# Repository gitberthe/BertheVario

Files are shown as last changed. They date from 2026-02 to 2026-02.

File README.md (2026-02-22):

# Projets BertheVario/GnuVario, BertheVarioTac et BertheVario213. 
Vario Gps parapente developés en C/C++ sous Platformio/VisualStudioCode/Code::Blocks (Software). kicad/freecad (Hardware).

**BertheVario/GnuVario :**
- firmware pour GnuVario (https://prunkdump.github.io/GNUVario-TTGO-T5-website/0-Accueil.html)
- carte mere indisponible donc pour mise a jour vario existant uniquement.
- socle pour les fichiers commun des 3 vario.

**BertheVarioTac :**
- Vario a base de ESP32-2432S028 sans la coque.
- un peut lourd pour voler et moindre autonomie d'alimentation.

**BertheVario213 :**
- Vario et coque imprimable 3d a base de Lilygo GDEM0213T5BN.
- le plus abouti des 3 vario.

**Photo des 3 vario :**

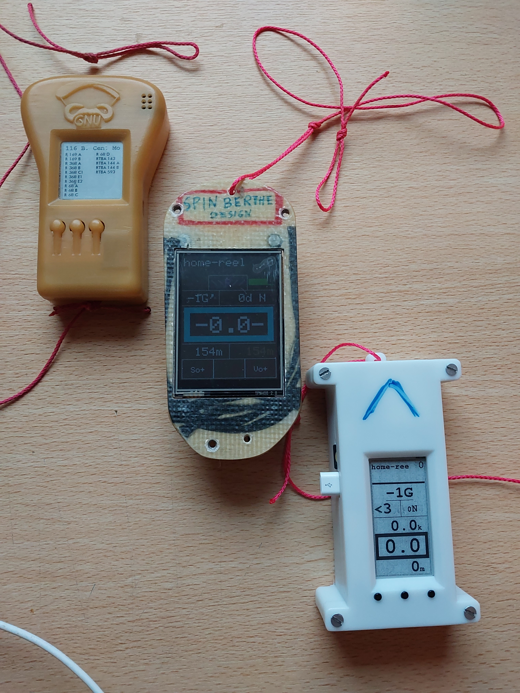
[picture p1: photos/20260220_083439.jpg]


**Logiciels annexes :**
- CompZoneAerienne : logiciel pour la creation du fichier de zone aerienne (TMA, CTR...). Visualisation des zones par fichier *.png et *.kml :
- GestHgt : logiciel pour les fichier *.hgt d'altitude sol (filtre france) et creation/verification checksum.
- IgcReader : logiciel pour relire succinctement un fichier igc (Z deco, Z attero ...) et le transformer en .kml pour googleearth.
- igc2kmz : logiciel python disponible sur le web pour creer un fichier .kmz googleearth, a partir d'un .igc (couleur fonction de Vz, altitude...) :

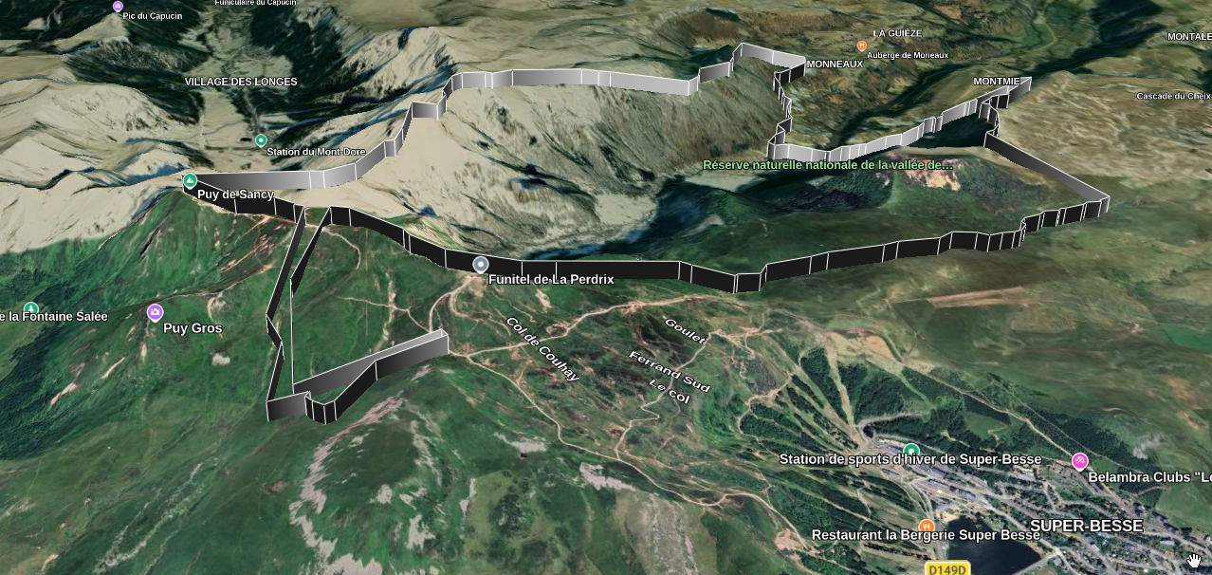
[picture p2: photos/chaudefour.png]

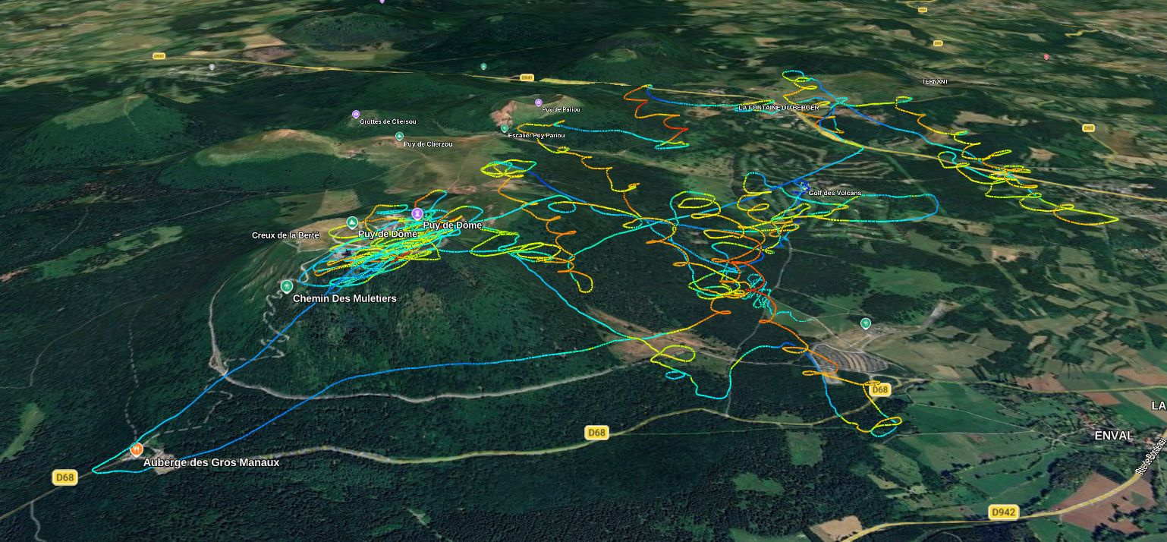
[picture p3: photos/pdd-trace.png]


zenodo :
https://doi.org/10.5281/zenodo.18722633

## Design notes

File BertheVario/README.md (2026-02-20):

# Projet BertheVario
Firmware récent du GnuVario (https://prunkdump.github.io/GNUVario-TTGO-T5-website/).
- Code C++ Visual Studio/PlateformIO pour alti-vario gps parapente (avec gestion des TMA CTR...).
- Plateforme Espressif ESP32 Dev Module, TTGO T5, Lilygo v2.4, Arduino (processeur 32bits, bi-core 240mhz).

**Utilisation / description :**
- documentation utilisateur dans /doc
- projet PlateformIO dans /BertheVarioPlatformIO
- editer/modifier avec codeblocs dans /BertheVarioCdb
- documentation developpeur dans ../../DoxyBertheVario avec le commande "doxygen Doxyfile.BertheVario" depuis /Codeblocks
- generation de fichier de zones aériennes avec /CompZoneAerienne depuis codeblocks/linux ou windows

**Important :**
- penser à bien modifier votre fichier de configuration pour un fonctionnement correct. En particulier le coefficient du filtre alti-baro (valeurs par defaut dans la documentation ou lorsque le fichier est absent/recréé mode mini-éditeur)

**Pour les développeur :**
- voire la documentation doxygen generée.
- modifier le #define de configuration du capteur magnetique pour position a plat, suspente droite ou gauche.
- fichier version.txt pour modification apportées aux differentes versions.
- modifier "BertheVarioPlatformIO/.pio/libdeps/esp32dev/ESP32 File Manager for Generation Klick ESPFMfGK/src/ESPFMfGKGa.cpp" ligne 6 : crc32.h => CRC32.h
- modifier "BertheVarioPlatformIO/.pio/libdeps/esp32dev/MPU9250/MPU9250.h" ligne 85 : 0x06 => 0x02

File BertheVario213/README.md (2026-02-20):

# Projet BertheVario213

Projet d'alti vario gps parapente (avec gestion des TMA CTR..., et mode guidage sol pour randonnée).
- Code C++ Visual Studio/PlateformIO.
- Plateforme Espressif ESP32 Dev Module, LILYGO T5 v2.3.1 GDEM0213T5BN 9102 chip, écran 2.13inch DEPG0213BN, Arduino (processeur 32bits, dual core, 240Mhz).

**La carte avec son pcb :**

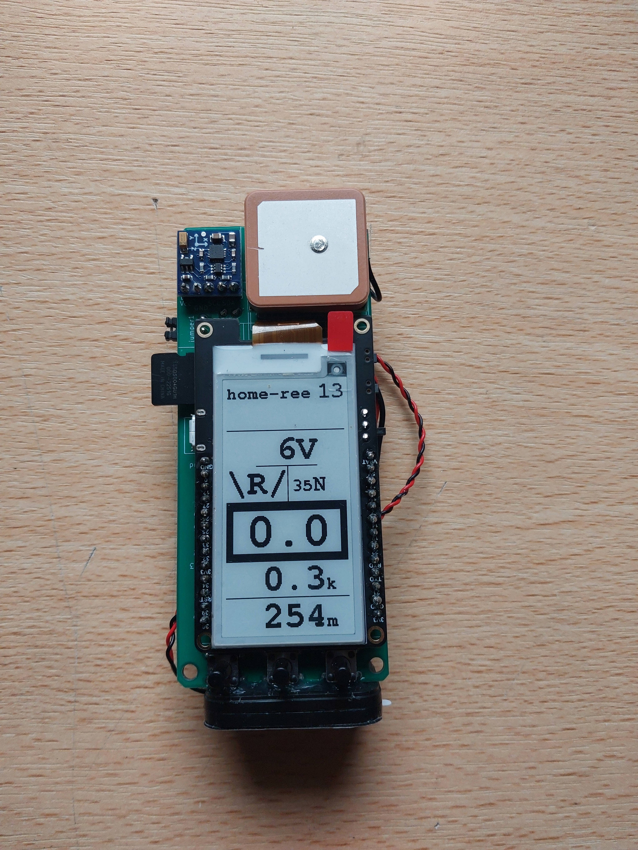
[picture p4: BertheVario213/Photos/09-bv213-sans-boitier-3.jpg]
  

**Le schema electrique :**

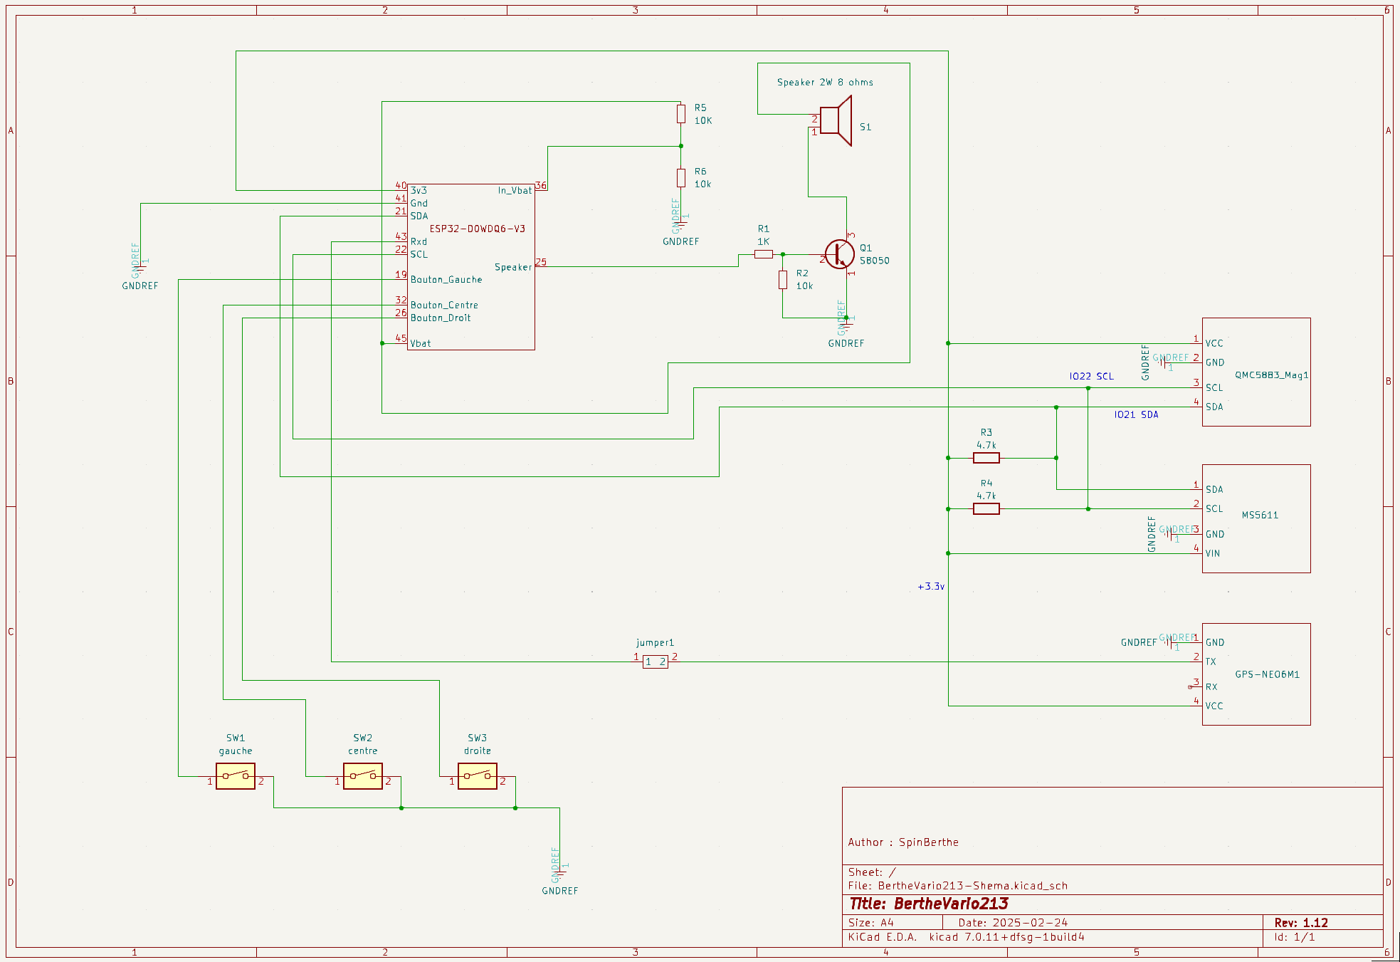
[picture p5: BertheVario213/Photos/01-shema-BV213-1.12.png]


**Le pcb :**

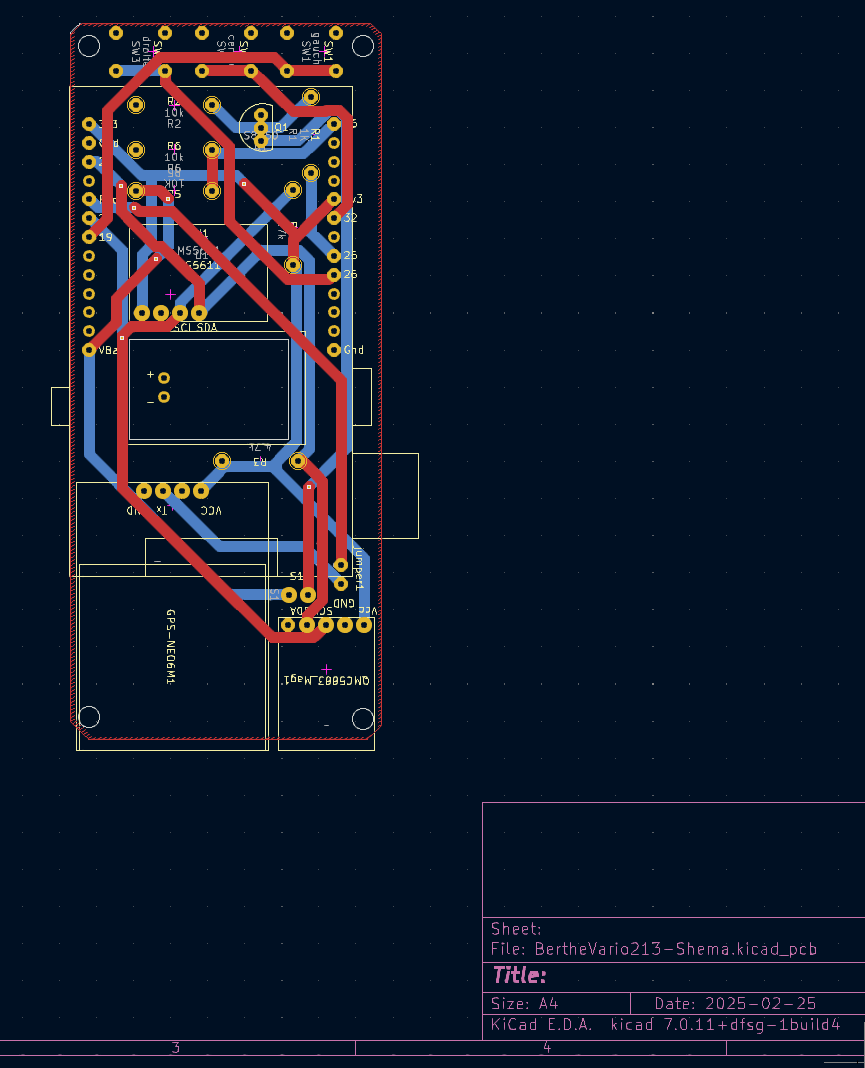
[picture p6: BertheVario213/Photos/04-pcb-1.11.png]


**Le mode randonnée :**

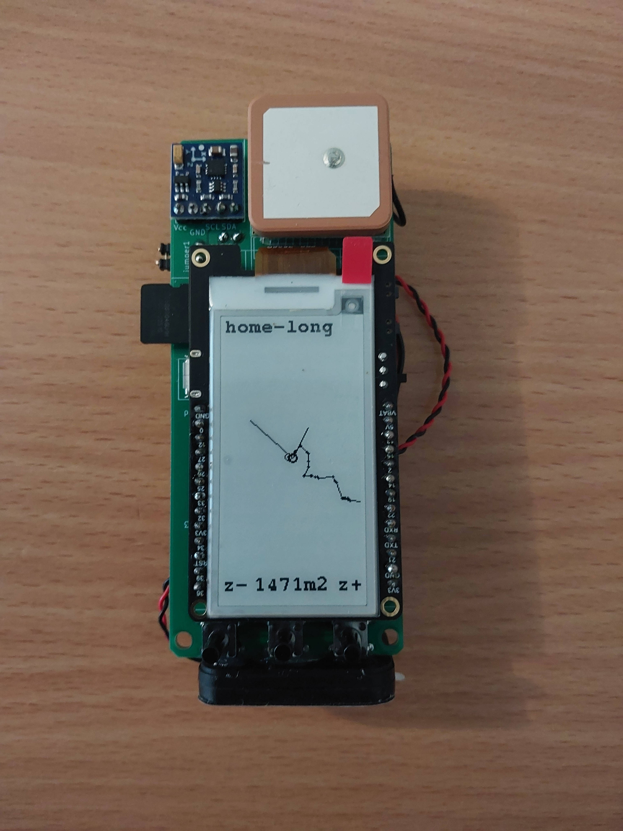
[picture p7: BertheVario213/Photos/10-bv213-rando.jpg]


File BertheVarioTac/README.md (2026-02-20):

# Projet BertheVarioTac ESP32-2432S028
Projet d'alti vario gps parapente tactile (avec gestion des TMA CTR..., et mode guidage sol pour randonnée).
- Code C++ Visual Studio/PlateformIO.
- Plateforme Espressif ESP32 Dev Module, 2.8inch ESP32-2432S028, Arduino, ESP32-WROOM-32,  (processeur LX6 32bits, bi-core 240mhz).

**Utilisation / description :**
- documentation utilisateur et autre dans /documentation
- projet PlateformIO dans /BertheVarioTacPlatformIO
- editer/modifier avec codeblocks dans /Codeblocks
- documentation developpeur dans ../../DoxyBertheVarioTac avec le commande "doxygen Doxyfile.BertheVarioTac" depuis /Codeblocks

**Pour les développeur :**
- voir la documentation doxygen generée.

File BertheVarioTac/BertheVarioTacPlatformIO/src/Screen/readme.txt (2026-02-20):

Fichier necessaires à la compilation de l'ecran :
 cp ./src/Screen/User_Setup.h ./.pio/libdeps/esp32dev/TFT_eSPI/User_Setup.h
 cp ./.pio/libdeps/esp32dev/LovyanGFX/examples/Advanced/LVGL_PlatformIO/src/lv_conf.h src/Screen

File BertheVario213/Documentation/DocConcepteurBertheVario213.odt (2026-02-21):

Documentation Concepteur BertheVario213

Projet d’alti vario gps parapente

à base de

LILYGO T5 v2.3.1 DEPG0213BN 9102 chip

Version 20260219a

https://github.com/gitberthe/BertheVario

Compilé avec Visual Studio Code / PlatformIO

Espressif Systems

ESP32 Dev Module

ESP32-D0WDQ6-V3

écran 2.13inch DEPG0213BN

Arduino

langage C++.

gitberthe@gmail.com

# Mise en place de l’environnement logiciel :

Le logiciel est compilé avec Visual Studio Code / PlatformIO.

* La librairie pour le gestionnaire de fichier Wifi doit être modifiée si la version est trop vieille.

Dans BertheVarioTacPlatformIO/.pio/libdeps/esp32dev/ESP32 File Manager for Generation Klick ESPFMfGK/src/ESPFMfGKGa.cpp" ligne 6 : crc32.h => CRC32.h

La compilation du logiciel peut alors s’effectuer.

# Connexion de la batterie :

Connecter la batterie à la carte ESP32 à l’aide du connecteur fournit. Une batterie 4,2v 1S lipo 2000 mah 103450 est suffisante. Elle se recharge par le connecteur usb.

# haut parleur :

Le haut parleur est un haut parleur 2W 8 ohms.

# Téléchargement du firmware :

Pour télécharger le firmware il y a 2 façons :

- soit par câble usb avec platformio ou un autre logiciel. Il faut impérativement retirer le cavalier de la donnée gps pour que le téléchargement se face.

- soit par wifi et carte sd. Il faut alors mettre le fichier BertheVario213/BertheVario213PlatformIO/p_pio/build/esp32dev/fimrware.bin à la racine de la carte SD. Puis rebooter avec les boutons gauche et droit. Lors du prochain demmarrage le vario ce mettra à jour puis rebootera.

# Quelques photos :

La carte de base ESP32 LILYGO T5 v2.3.1 GDEM0213T5BN 9102 chip avec son écran 2,13 inch DEPG0213BN:

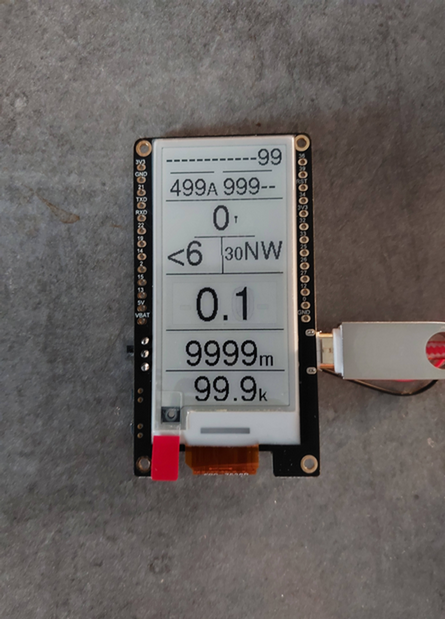
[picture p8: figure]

Attention : Prévoir un film filtre uv car il ne résiste pas au soleil cet écran.

Le circuit imprimé avec ses composants sur les 2 faces. Attention au sens du gps, capteur magnétique, barométrique, et transistor.

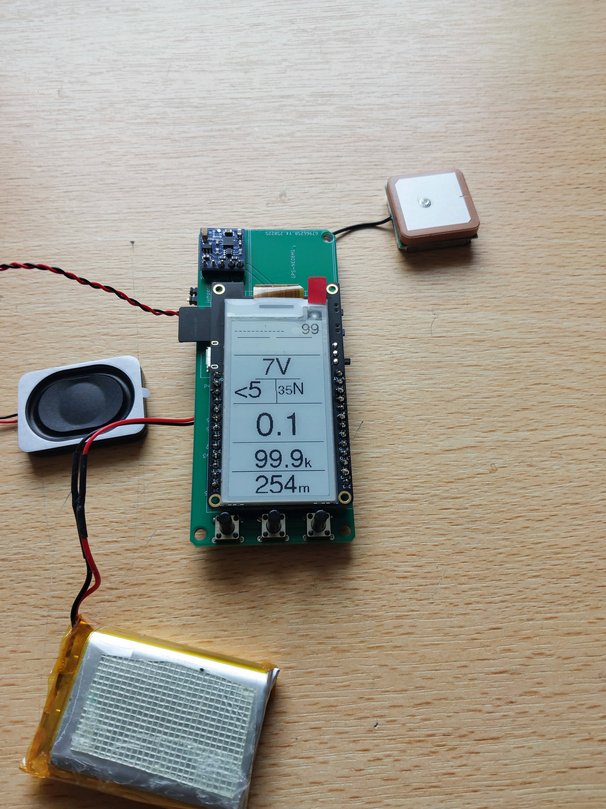
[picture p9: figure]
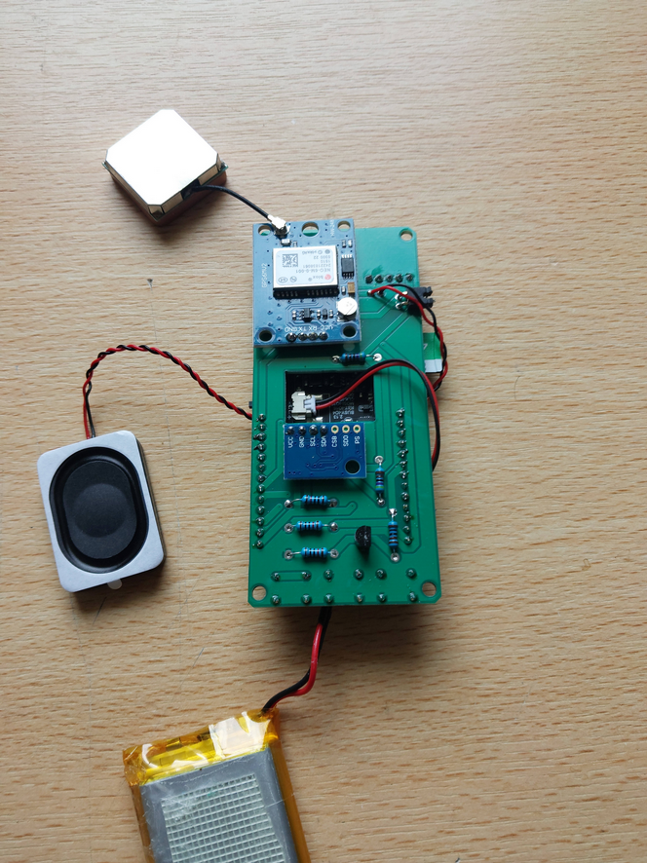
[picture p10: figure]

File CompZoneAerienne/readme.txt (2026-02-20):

projet pour creer le fichier des zones aeriennes.

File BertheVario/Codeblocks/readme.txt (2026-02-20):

- Ce repertoire est present uniquement pour editer/modifier les sources sous codeblocks
- utilisation aussi pour generer la documentation code dans ../../DoxyBertheVario : doxygen Doxyfile.BertheVario

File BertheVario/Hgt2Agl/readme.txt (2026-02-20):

projet pour tester les fichier *.hgt hauteur sol.

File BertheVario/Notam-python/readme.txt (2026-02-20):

!!!! projet non fonctionnel !!!!

- script python pour extraire les notams du site sofia-briefing
- en colaboration avec c.joyez@free.fr

- a poursuivre : saisie de la date, heure et nom aeroport de depart en parametre de la ligne de commande

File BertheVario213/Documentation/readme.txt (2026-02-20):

Documentation utilisateur pour description de l'ihm, des boutons et des fichiers de la carte sd.
Documentation concepteur pour description succinte de l'environnement lociciel et du telechargement firmware.

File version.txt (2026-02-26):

le 20260226a :
 - hauteur sol attero 90m pour les 3 vario
 - son vario pour BertheVario213

le 20260223a :
 - mise en conformite de BertheVarioTac pour le regroupement de l'activation 
   de zones.

le 20260220a :
 - creation de https://github.com/gitberthe/BertheVario pour les 3 varios : 
  . BertheVario/GnuVario
  . BertheVarioTac
  . BertheVario213

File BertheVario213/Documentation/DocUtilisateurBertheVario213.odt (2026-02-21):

Documentation Utilisateur BertheVario213

Projet d’alti vario gps parapente

à base de

LILYGO T5 v2.3.1 DEPG0213BN 9102 chip

Version 20260219a

https://github.com/gitberthe/BertheVario

Compilé avec Visual Studio Code / PlatformIO

Espressif Systems

ESP32 Dev Module

ESP32-D0WDQ6-V3

écran 2.13inch DEPG0213BN

Arduino

langage C++.

gitberthe@gmail.com

Modifications apportées à la documentation :

20260219a : Modification Ihm.

20250322b: Chapitre 21 mode randonnée.

20250322a: Création documentation utilisateur d’après BertheVario.

# Écran de boot :

A l’écran de boot, il y a possibilité de changer de mode (voir boutons plus bas). Puis il y a affichage de la tension de batterie, du pourcentage batterie et du numéro de firmware.

Une batterie à 4,3v est chargée, à 3,7v vide.

Initialisation du hardware : 1 beep, à la mise sous tension.

Remarque 1 : en mode connexion wifi, les identifiants sont ceux stockés sur la carte SD dans le fichier /config/config.txt.

En mode connexion wifi, il suffit de taper dans un navigateur web http://x.x.x.x:8080 (adresse IP données par l’écran) pour avoir accès à la page téléchargement si dessous (accès au fichiers IGC par clic sur le lien, éditer, renommer. détruire, prévisualiser.)

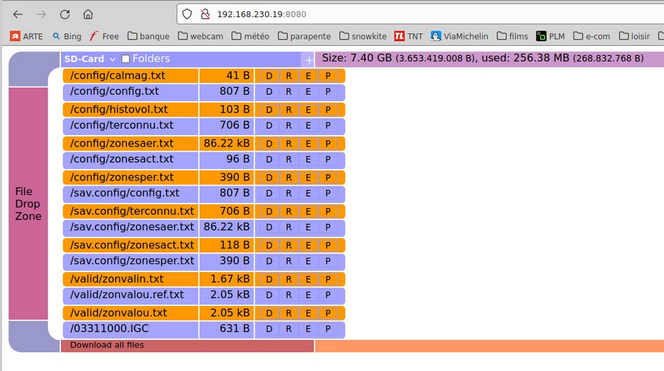
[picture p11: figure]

Remarque 2 : En mode calibration du capteur magnétique. Il faut faire des 8 avec le BertheVario213 jusqu’à re-démarrage (maximum de directions possible dans le sens du cap magnétique).

Il y a mise a jour du fichier /config/calmag.txt sur la carte SD qui est nécessaire au bon fonctionnement du capteur magnétique.

Bien sur, faire des 8 en position à plat ou verticale suivant la configuration firmware “à plat” “ou “suspente gauche ou droite”.

Remarque 3 : Dans les pages ihm du milieux, si on appuie sur le bouton gauche et droit, mais pas sur le bouton centrale, il y a alors reboot du BertheVario213.

Boutons :

Gauche : mode calibration.

Central : mode wifi.

Droit : mode rando-vol. Ou verification cheksum des *.hgt si appuy multiple.

Gauche et droit : reboot.

# Démarrage :

Après le boot et l’initialisation du hardware, il y a démarrage du logiciel et 2 beep. S’il y a 4 beep, c’est qu’il y a un problème de carte SD. Puis il y a affichage de l’écran 0 Vz.

# Écran Vz :

Cap Magnétique

à plat

Nom terrain et finesse

Temps de vol

Tension batterie

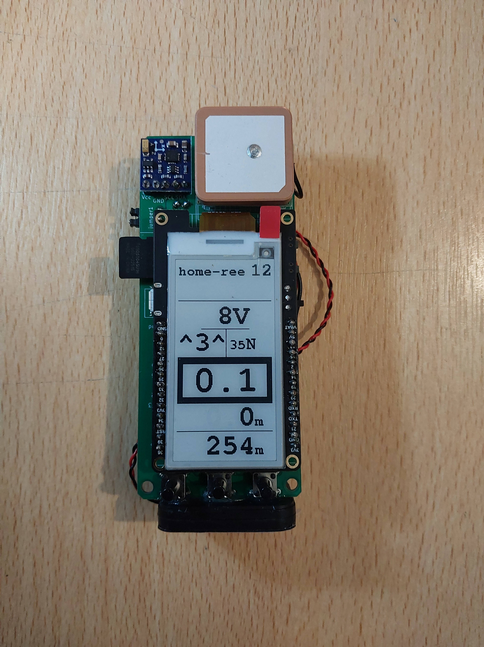
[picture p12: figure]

Cap Sol/Gps

Dérive Sol

Vitesse verticale / finesse sol

Altitude/Hauteur sol

Vitesse Sol

Bouton central

Bouton gauche

Bouton droit

Important : Un appui long sur le bouton centre permet de re-effacer l’écran pour le remettre propre.

Boutons :

- gauche court : activer/désactiver le son d’attente gps G/S/V et/ou alarmes/pré-alarmes pénétration Tma/Zones.

- gauche long : page précédente (bloqué en vol).

- central : page suivante (bloqué en vol).

- central long : raz de l’écran.

- droit court/long: démarrage forcé du vol ( Gps mode S/V) / arrêt du vol ( si < 5kmh et 0,4m/s).

Cap magnétique : le cap est indiqué suivant la direction de la flèche. Il doit avoir été calibré au moins une fois (fichier /config/calmag.txt, voir séquence de boot)

Dérive sol : la dérive sol est indiquée en dizaine de degrés <<4 gauche, 5>> droite ou ^1^ tout droit. \R/ indique une reculade avec alarme sonore désactivable. Gauche indique que l’on dérive a gauche par rapport au cap magnétique.

Nom terrain et finesse / direction et distance du terrain : Indique le nom du terrain d’atterrissage le plus proche et sa finesse pour l’atteindre.

Cap sol : cap issue du gps en dizaine de degrés. Indication Nord, Nord Est ...

Vitesse sol : vitesse issue du gps en km/h. Hauteur sol barométrique en mètres.

Vz : Vz du capteur barométrique. Si la Vz est cerclée de noir c’est qu’elle est négative.

Altitude : Altitude barométrique recalée altitude sol en mètres. Le recalage sol est effectué toutes le 10 sec au sol avec l’emmission d’un bip caracteristique. A verifier au moment de la pré-vol.

Temps de vol : Temps de vol en minutes.

‘-1G’ indique une attente de données GPS (voyant rouge clignotant) (émission d’un bip toutes les 5 secondes).

‘ 8S’ indique une attente de stabilisation des informations longitude, altitude, 8 satellites en vue (émission d’un bip toutes les 5 secondes).

‘10V’ indique une attente de la vitesse sol importante pour le démarrage de l’enregistrement du fichier IGC de trace GPS, 10 satellites en vue. (émission de 2 bips toutes les 5 secondes si pas hinibé avec le bouton gauche)

Les fichier IGC générés sont sous la forme MMJJHHmm.IGC dans la carte SD à la racine au rythme d’un point par seconde.

Émission de 3 beep au démarrage de l’enregistrement IGC.

Il peut y avoir arrêt de vol et redémarrage des taches en mode “S” (3 bips) si l’on ne vol plus pendant 4 secondes (vitesse sol petite, hauteur sol petite...)

Il y a aussi arrêt du vol si on appui sur la touche droite.

Nom terrain et finesse : Conformément au fichier “/config/terconnu.txt” de la carte SD. Affichage du terrain accessible avec la plus petite finesse. Et affichage de la finesse pour l’atteindre.

Remarque 1 : Il y affichage de la TMA/CTR/Zone protégé pénétré (avec son altitude) à la place du nom terrain finesse si l’on est dedans une zone (voir fichier /config/zonesaer.txt). (3 bips caracteristiques si dans la zone).

Be TMA 5.1 al:3500m indique que l’on est en “below” en dessous de la TMA 5.1 qui commence a une altitude de 3500m ce jour.

In TMA 2.3 al:1980m indique que l’on est en “in” on a pénétré la TMA 2.3 qui commence a une altitude de 1980m.

Zp PROTECT Reserve naturelle al: 0m indique que l’on a pénétré une zone protège (en dessous de 1000/ … /50m sol).

Remarque 2 :On peut déclencher un début de vol par le bouton droit en écran Vz (sans stabilisation gps). On peut arrêter un vol aussi par le bouton droit si la vitesse sol est < 5kmh et la Vz < 0,6m/s.

# Écran Histo:

On accède à l’écran Histo par un appui sur le bouton centre après l’écran Vz. L’écran revient à l’écran Vz au bout de 15 secondes.

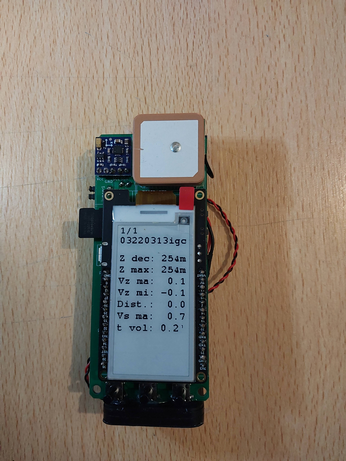
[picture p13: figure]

L’écran Histo contient le nom du fichier Igc, la Z décollage, la Z max, la Vz Max, la Vz Min, la distance parcourue, la Vs Max et le temps total du vol. Ces informations sont issues des fichiers “/histo/nom_igc.his”.

Boutons :

- gauche long : page précédente.

- central : page suivante.

- central long : raz de l’écran.

# Écran Affichage / Archivage IGC :

Ces 2 écrans entre les écrans historique du dernier vol et gestion des TMA permettent :

- pour l’écran affichage igc, affichage des temps des fichiers IGC sur la carte SD et calcul de leur total en minutes decimale (si vol supérieur à 30 secondes).

- pour l’écran archivage (bouton gauche/droite, permet d’archiver tous les fichiers IGC de la carte qui sont à la racine. Dans le répertoire /arch/annee. Destruction des vols < 1 min.

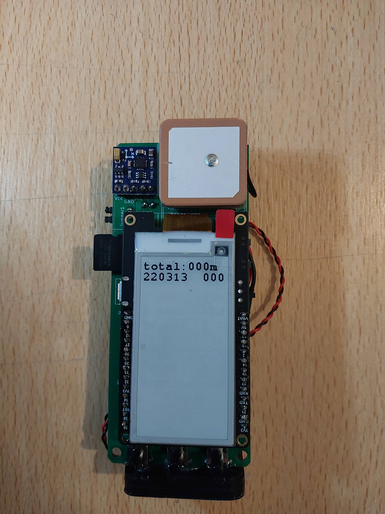
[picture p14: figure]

Boutons :

- gauche long : page précédente.

- central : page suivante.

- central long : raz de l’écran.

- gauche/droit : archivage fichier igc. (central annulation)

# Écran Zone Aériennes / Modification :

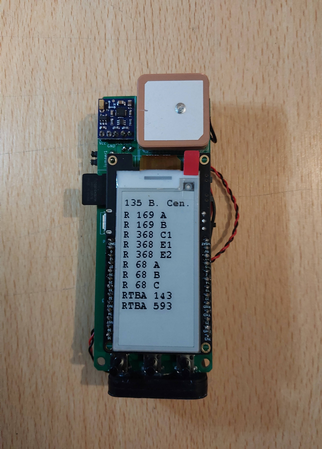
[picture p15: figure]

On accède à l’écran zone aériennes par un appui sur le bouton centre depuis histo. L’écran revient à l’écran 0 au bout de 15 secondes. Cet écran est pour la gestion des zones aériennes. On a le nombre de zones aériennes en mémoire, ainsi que le nom des zones modifiables activées. Celles non modificables ou désactivée ne sont pas affichées.

Depuis l’écran zone aérienne, avec un clic droit/gauche on passe à l’écran modification pour lire ou modifier l’activation des zones. L’écran revient à l’écran Vz au bout de 15 secondes. Les boutons gauche/droit font défiler les zones, le bouton centrale peut modifier l’activation de la zone en cour (si elle est mod et pas const). Pour les zone modifiables (ex :R68 ou R368) voir le fichier config/zonesact.txt)

Il y a affichage à l’écran modification des informations nom, activation modifiable (mod) ou figée (const), altitude basse hors période, période début JJ-MM, période fin JJ-MM, altitude basse période semaine, altitude basse période week-end. Si la zone est « protect » ou « ffvl-prot », affichage de la hauteur sol minimale de survole (ex : Chastreix, Chaudefour, Parc des Cevennes, Gypaete barbu...)

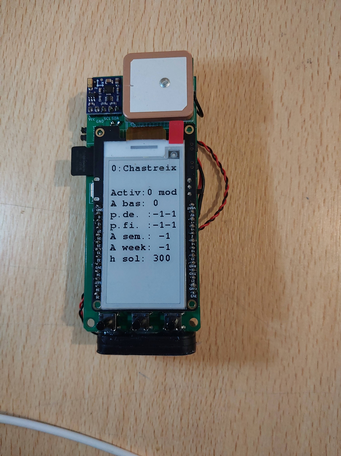
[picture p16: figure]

Boutons :

- gauche long : page précédente.

- central : page suivante. si mode navigation zone : activation/désactivation Tma/Zone

- central long : raz de l’écran.

- gauche/droite : mode navigation dans Tma/Zone et retour page Tma global.

- long G/D début/fin Tma/Zones si mode navigation Tma/Zone.

La modification de l’activation de la zone est mémorisée dans le fichier /config/zonesact.txt. Et seul les zones présente dans ce fichier sont modifiable. Le format est : nom_zone;0;. Il faut donc le générer une première fois avec un éditeur de texte, pour pouvoir le modifier par la suite.

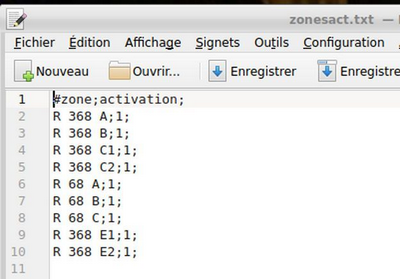
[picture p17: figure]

Remarque :

Les zones ne figurant pas dans ce fichier sont considérées comme toujours actives.

Il y a regroupement de zone suivant les 2 permier champ. Ex : R_68 modifiera R_68_A et R_68_B...

La totalité des zones sont dans le fichier /config/zonesaer.txt, voir plus bas pour le générer.

La configuration des périodes est dans le fichier /config/zonesper.txt. Il est de la forme :

nom zone;nom affichage;début période;fin période;alti semaine;alti week-end

ex : TMA CLERMONT 2.1;TMA CFD 2;15-03;15-10;1980;1980

Nom zone est le nom dans le fichier /config/zonesaer.txt, les 3 premiers champs. Nom affichage est le nom de remplacement à l’affichage, puis JJ-MM début période, JJ-MM fin de période, altitude période semaine, altitude période week-end.

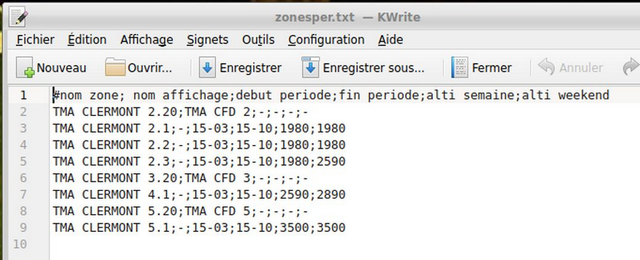
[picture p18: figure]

# Écran Éditeur Configuration:

On accède à l’écran éditeur par un appui sur le bouton centre après l’écran TMA. On a alors accès a un mini éditeur du fichier de configuration. On peut ainsi modifier les variable par bouton central, puis G/D pour incrémenter / décrémenter. Ex 1: [dtu] => augmentation/diminution de 1 avec les boutons. Ex 2 : [vz_seuil_haut] => augmentation/diminution de 0,05 avec les boutons C/G/D. Les modifications sont automatiquement pris en compte et sauvegardées dans le fichier de configuration /config/config.txt dès le retour à une autre page. S’il n’y avait pas de fichier, un fichier par défaut est créé.

Important :

Le coefficient de filtrage Vz doit etre à 0,85.

Boutons :

- gauche long : page précédente.

- central : page suivante. si mode navigation variables : mode modification/navigation variable.

- central long : raz de l’écran.

- gauche/droite : navigation dans variable et sortie de navigation variable. Incrémentation/décrémentation variable si mode modification.

- long G/D début/fin variable si mode navigation variable.

# Écran Tma Dessous:

On accède à l’écran Tma dessous par un appui sur le bouton centre après l’écran éditeur. On a alors accès à la Tma sous laquelle on est, avec son altitude. Ainsi que les coordonnées du point gps en cours.

Boutons :

- gauche long : page précédente.

- central : page suivante. Annulation mémorisation point.

- central long : raz de l’écran.

- gauche/droite : mémorisation point courant dans le fichier des terrains connus. Exemple : mémoriser un nouveau terrain d’atterrissage.

# Écran Système :

On accède à l’écran système par un appui sur le bouton centre âpres l’écran Tma dessous. L’écran revient à l’écran Vz au bout de 15 secondes. Cet écran est plus informations système avec date et heure, cap magnétique, pourcentage d’utilisation core 0 et 1, température à l’intérieur du boîtier, mémoire libre en octets, tension batterie, et numéro du firmware. Pour info, une zone aérienne prend de 1 à quelques ko suivant sa taille. Il y a donc de la marge dans le cas ci-dessous.

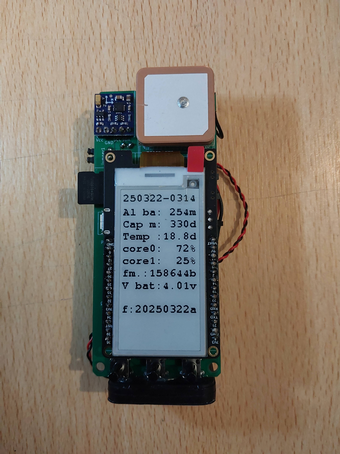
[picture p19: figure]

Boutons :

- gauche long : page précédente.

- central : page suivante.

- droit long :

# Fichier de configuration SDCard/config/config.txt :

Le fichier de configuration doit être placé dans le dossier /config a la racine de la carte SD. La carte SD contient aussi les fichier IGC générés par un vol (ou un faux vol de 12 secondes).

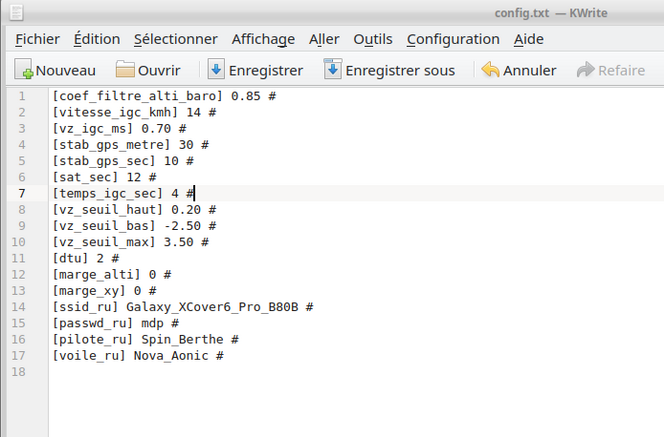
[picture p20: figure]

Compléter les informations nécessaires dans ce fichier. Les # sont des commentaires, pour le mot de passe, ssid, pilote et voile les ‘_’ sont remplacés par des blancs/espaces.

Le fichier est généré automatiquement si vous passer une fois en page mini éditeur s’il n’existait pas auparavant avec les valeurs par défaut.

[coef_filtre_alti_baro] : filtrage alti baro, valeur [0,1[, 0.999 donne un très grand filtrage mais un léger retard dans la valeur. 0. ne filtre rien et donne par conséquent des beep intempestifs. Mettre 0.85 pour un filtrage correct.

[vitesse_igc_kmh] : vitesse sol de déclenchement de l’enregistrement. Début de vol déclenché au bout de temps_igc_sec secondes de vitesse successive supérieur à (14km/h par défaut). S’il y a faux départs de vols cause imprécision gps, ne pas bouger le temps de la détection de stationnarité (quelques secondes). Il y a alors redémarrage des taches automatiquement en mode S/V.

[vz_igc_ms] : + ou - vitesse verticale pour déclencher un vol (0,6 par défaut).

[vz_seuil_haut] : Vz ascendante de déclenchement des beeps aiguës (0,2 par défaut).

[vz_seuil_bas] : Vz descendante de déclenchement des beeps grave (-2,6 par défaut).

[vz_seuil_max] : Vz ascendante des beep vario maximum très aiguës (4 par défaut).

[alarme_reculade] : activation alarme sonore reculade (désactive par défaut).

[ssid_ru] : nom wifi pour téléchargement des IGC via navigateur web. (underscores remplacés par des espaces)

[dtu] : heure a ajouter a l’heure gps pour le nom des fichiers *.igc.

[passwd_ru] : mot de passe wifi (underscores remplacés par des espaces)

[pilote_ru] : nom de pilote dans le fichier igc (underscores remplacés par des espaces)

[voile_ru] : nom de voile dans le fichier igc (underscores remplacés par des espaces)

# Fichier de terrains connus SDCard/config/terconnu.txt :

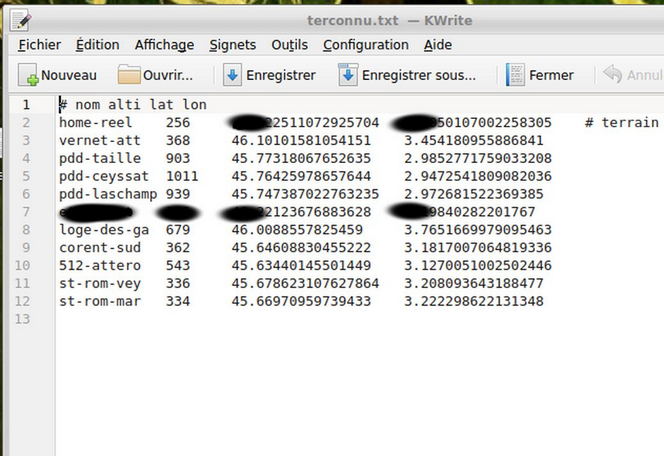
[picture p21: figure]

Comme vous pouvez le voir, ce fichier liste les terrains connus avec leur nom de 10 caractères maximum ainsi que leur coordonnes. Utile pour avoir la finesse du terrain le plus proche. Et pour générer les zones aériennes autour de ces points.

De plus ce fichier peut etre utilisé pour generer les zones aériennes (rayon autour des points)

# Fichier de calibration SDCard/config/calmag.txt :

Ce fichier est généré automatiquement par appuis au boot sur le bouton gauche. Faire des 8 avec le boîtier jusqu’au redémarrage pour calibrer le capteur magnétique.

# Fichier d’historique de vol SDCard/config/histovol.txt :

Ce fichier est généré automatiquement à chaque nouveau vol. Il est lu pour afficher l’écran 1. Sa forme est la même que celle dur fichier “/config/config.txt”.

# Fichier IGC :

Les fichier IGC sont téléchargeable en mode wifi (voir séquence de boot) et peuvent être visualisés sur le web avec https://e-logbook.org par exemple. Ils contiennent les date et position pour chaque seconde. L’altitude GPS qui est fausse a 50m près souvent, c’est pour cela que je ne la met plus. Il contient aussi l’altitude barométrique qui est recalée altitude sol pendant la phase S stabilisation (il est donc important de laisser le vario au sol pendant cette phase). Cette dernière est assez précise (10cm normalement) pour peut que l’on ai laissé le GPS immobile pendant la phase S, le temps qu’il se cale bien en lat/lon pour extraire la bonne altitude des fichier *.hgt. On a alors un fichier IGC précis à quelques mètres. Que l’on peut convertir en kml avec http://meles.work/igc/igc.html.

# Carte SD :

La carte SD doit etre formaté en fat16/fat32 les fichiers “/config/terconnu.txt”, “/config/config.txt”, “/config/calmag.txt”, “/config/zonesaer.txt”, “/config/zonesact.txt” et “/config/zonesper.txt”. Et les fichiers generes “/config/calmag.txt” et “/histo/nom_igc.his”. Les fichiers *.IGC sont créées à la racine.

Elle contient aussi les fichiers de validation de zone “/valid/zonvalin.txt” et le fichier généré au boot wifi “/valid/zonvalout.txt”.

Important : Pensez a installer aussi les fichier de hauteur sol *.hgt, pour toute la france, dans le repertoire "/config/hgtdata". Ceci est obligatoire car il y a recalage d’altitude barométrique avec ces fichiers avant le decollage ( https://www.viewfinderpanoramas.org/Coverage%20map%20viewfinderpanoramas_org3.htm ).

# Rechargement du GnuVario :

Utiliser un cable micro-usb. Une recharge complète prend plusieurs heures. La tension de la batterie doit être à 4,3v en pleine charge (3,7v déchargée). La tension de la batterie est affichée a l’écran de boot ou en page sys, ainsi que en page Vz par le train en gras au dessus du temps de vol.

# Le Gps :

Bien entendu le Gps accroche mieux en pleine nature qu’en ville, en terrain découvert que sous les arbres, par ciel clair que pluvieux, à l’arrêt qu’en déplacement. Attendre l’affichage d’une altitude cohérente à l’écran avant de faire le vol (recalage altitude barométrique par altitude sol jusqu’à la stabilisation gps).

# Les zones aériennes et le fichier SDCard/config/zonesaer.txt :

Les zones aériennes qui sont traversées sont affichées en lieux et place de “terrain connu accessible”. Si l’on traverse une zone aérienne, il y a affichage du nom de la zone ainsi de que sont altitude minimale avec une alarme sonore (l’altitude est fonction de la zone, de la date en ou hors périodes, et de la semaine ou du week-end dans la période). L’alarme sonore est activable/désactivable par le bouton du milieu.

Peut de zones tiennent en mémoire du GnuVario. Donc, pour ce faire, il faut prendre le fichier PlatformIO/Projects/CompZoneAerienne/data/20240615_ffvl-cfd.geojson (disponible sur le net, fichier generer par “Pascal Bazile” http://pascal.bazile.free.fr/paraglidingFolder/divers/GPS/OpenAir-Format/download.php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 ) et le découper avec le programme PlatformIO/Projects/CompZoneAerienne/CompZoneAerienne qui compresse les zones à fort nombre de points (itération 3 points distance à la droite < 4,5 mètres) ..

Utilisation : CompZoneAerienne lat_centre_deg lon_centre_deg rayon_km > zonesaert.txt. Ou CompZoneAerienne –batch terconnu.txt rayon_km > zonesaert.txt pour utilisation du fichier des terrains connus. Le programme enregistre alors dans le fichier toutes les zones coupant les cercles définit par leur centres et rayons des points connus. Il suffit de placer ce fichier sur la carte SD/config.

Attention : Si le fichier est trop gros, il plante le GnuVario au boot lors de sa lecture. C’est pour cela qu’il y a des zones réduites en nombre de points par CompZoneAerienne, Ceci est fait lors de la génération du fichier. Comme pour les zones protégées “PROTECT” qui ont un énorme nombre de points de définition (1800 pour Chaudefour)(Validation Gnuplot très acceptable). L’algorithme utilisé est la suppression des points proches d’une droite.

De plus, pour gagner en mémoire il y a un algorithme de compression de données de float 32bits vers short 16bits dans le firmware. Les zones ont ainsi une résolution variable de 1 à 7 mètres par rapport aux zones du fichier. En moyenne la résolution est de 1,95metres. Si il y a un problème de compression short il y a beep et reboot.

Remarque : Les fichiers *.hgt nécessaire au calcul de la hauteur sol sont a mettre dans le répertoire “SdCard/config/hgtdata” (à télécharger sur https://www.viewfinderpanoramas.org/Coverage%20map%20viewfinderpanoramas_org3.htm). Il y a test de présence au démarrage du centre de la France.

Important : Le GnuVario a été activement teste pour différent sites d‘Auvergne, a différentes périodes, altitudes et marges XY Z. Je décline toutes responsabilité quand à sa fiabilité à ce sujet (on est jamais à l’abri d’un oubli dans l’algorithme), en Auvergne et encore moins dans une autre région. Les zones étant bien imbriquées, vérifier par procédure de test, au moins un point par zone, que le comportement est correct chez vous. Pour cela il y a 2 façons :

- Rappel : dans la page “histo ecran 1”, la zone et le plafond courant sont affichés.

- Utiliser le fichier /valid/zonevalin.txt de la carte Sd. Puis booter en wifi. Il y a alors génération de /valid/zonevalou.txt avec les résultats.

Zonevalin.txt est de la forme :

#ville;lon,lat;annee,mois,jour;altitude,marge_xy,marge_z;zone a_active,zone_b_active;

Zonevalou.txt est de la forme :

numéro_ligne;ville;date;TMA;altitude_plafond;alarme_générée;

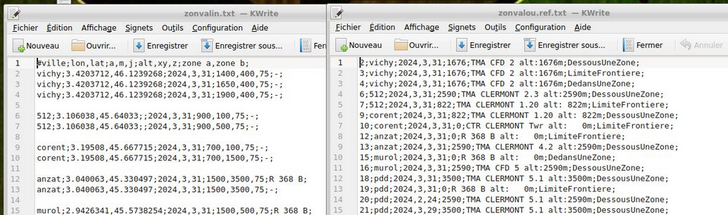
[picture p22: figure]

Remarque :

Voir le logiciel CompZoneAerienne/zones_gnuplot et zones_kml pour avoir le dessin des zones. Sous forme de fichier *.png ou *.kml pour google earth.

# Pour les développeur :

Pour ceux qui veulent recompiler le programme pour leur écran ou autre. Installer Visual studio code sur linux (ou Windows) comme préconiser sur https://prunkdump.github.io/GNUVario-TTGO-T5-website/code/ide_platformio.html (avec plateforme IO et board espressif ESP32 Dev module).

Copier les dossiers de https://github.com/gitberthe/BertheVario213 dans ~/Documents/PlatformIO/Projets.

Ouvrir le projet BertheVario213PlatformIO. Modifier les fichiers désirer, et en particulier les // commentaires dans les fichier BertheVario213PlatformIO/src/BertheVario213.h et ses différents #define DEBUG_XYZ.

Puis compiler/uploader le firmware (petite fleche en bas à gauche de VSCode, port /dev/ttyACM0 sous linux) de préférence sans la carte SD. Ca reboot automatiquement le BertheVario213.

Débogage par “Moniteur Serie”.

Important : attention si vous réinstallé VsCode (apparemment avec github et pull):

- modifier "BertheVario213PlatformIO/.pio/libdeps/esp32dev/ESP32 File Manager for Generation Klick ESPFMfGK/src/ESPFMfGKGa.cpp" ligne 6 : #include <crc32.h> en <CRC32.h>.

Rappel : Pour ceux qui veulent recompiler CompZoneAerienne et ainsi générer leur propre zones, le faire sous codeblocks, aussi bien sous windows que sous liux.

Pour windows voir le programme et ses .dll déjà compilées dans le dépôt https://github.com/gitberthe/BertheVario213

# Le mode randonnée pour ne plus se perdre :

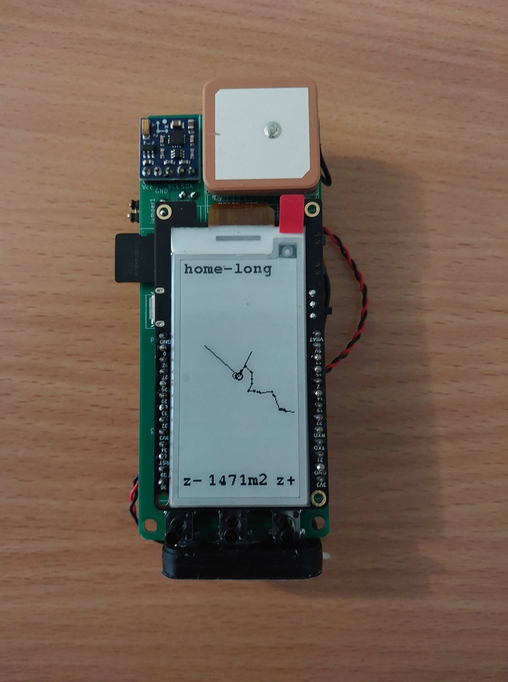
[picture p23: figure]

Trace du fichier Gpx

Echelle de la carte

Nom trace courante

Zoom + et -

Nord magnetique

Cap Gps

Position courante

Le mode randonnée est un mode de guidage terrestre pour rejoindre un décollage inconnu par exemple.

Il est accessible au boot par l’appui sur le bouton droit (rappel : gauche calibration magnétique, centre filemanager wifi, gauche et droite reboot).

Au démarrage, il y a acquisition du Gps. Puis une fois le Gps fonctionnant, il y a lecture des fichiers *.GPX du répertoire /SdCard/Gpx, ainsi que du fichier des terrains connus et d’un fichier similaire ptremarq.txt. Et affichage quelques secondes des traces/points les plus proches (rappel on peut télécharger les fichiers par wifi, drag&drop).

Suivant la position Gps, la trace/point gpx la plus proche est chargée en mémoire au bout de quelques secondes. On peut sélectionner une autre trace par les boutons gauche/droite/centre. Le guidage alors commence.

A l’écran on a :

- Le nom de la trace du fichier gpx (8 caractères maximum + 3 pour l’extension). Le nom de la trace est celui dans le fichier (la balise <name>) et peut être modifiée avec un éditeur de texte standard.

- La grande ligne est le nord magnétique issu du capteur magnétique (qui doit être calibré bien sur). Dans mon cas le haut du BertheVario213 mais ça dépend de la compilation (fichier BerheVario213.h #define VARIO_CAP_MAG_A_PLAT 1 2 ou 3).

- La trace gpx, orientée au nord, à l’échelle indiquée en mètres carrés pour la surface de l’écran.

- Les touches gauche/droite pour zoom fois 2, divisé par 2.

- le centre de l’écran est la position actuelle.

- La petite ligne est le cap gps.

Donc en alignant le nord magnétique en haut de la carte on peut se situer par rapport à la trace. Le petit rond de la trace indique le début de la trace. Pour ma part c’est souvent l’atterrissage.

On peut aussi mettre la ligne du cap gps en direction de la trace pour la rejoindre. Ou parallèle à la trace pour la suivre.

D’autre part, avec le bouton centre, on affiche la page informations pour quelques secondes. Avec les distances/altitudes positive faites et restantes.

On peut aussi orienter la carte au cap gps lors de la marche (boutons long G/D ou double appui).

Je crée souvent les traces avec https://www.visugpx.com/editgpx.

Boutons :

Centre : validation trace si menu. page info rando si mode trace.

Centre long : raz écran.

Gauche/Droite : sélection trace si menu. Zoom+/-.

Gauche/Droite long : cap nord/gps.

A vos bâtons de marche...

et

Bon vols.

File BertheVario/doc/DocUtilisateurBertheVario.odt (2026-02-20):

Documentation Utilisateur BertheVario

Projet de firmware récent issue de :

https://prunkdump.github.io/GNUVario-TTGO-T5-website/0-Accueil.html

Version : 20260210a

https://github.com/gitberthe/BertheVario

Compilé avec Visual Studio Code

Espressif Systems

ESP32 Dev Module

TTGO T5 Lilygo v2.4 Arduino

langage C++.

gitberthe@gmail.com

Modifications apportées à la documentation :

20260210a: Reprise de la documenation.

# Écran de boot :

A l’écran de boot, il y a possibilité de changer de mode (voir boutons plus bas). Puis il y a affichage de la tension de batterie, du pourcentage batterie et du numéro de firmware.

Une batterie à 4,3v est chargée, à 3,7v vide.

Initialisation du hardware : 1 beep, à la mise sous tension.

Remarque 1 : en mode connexion wifi, les identifiants sont ceux stockés sur la carte SD dans le fichier /config/config.txt.

En mode connexion wifi, il suffit de taper dans un navigateur web http://x.x.x.x:8080 (adresse IP données par l’écran) pour avoir accès à la page téléchargement si dessous (accès au fichiers IGC par clic sur le lien, éditer, renommer. détruire, prévisualiser.)

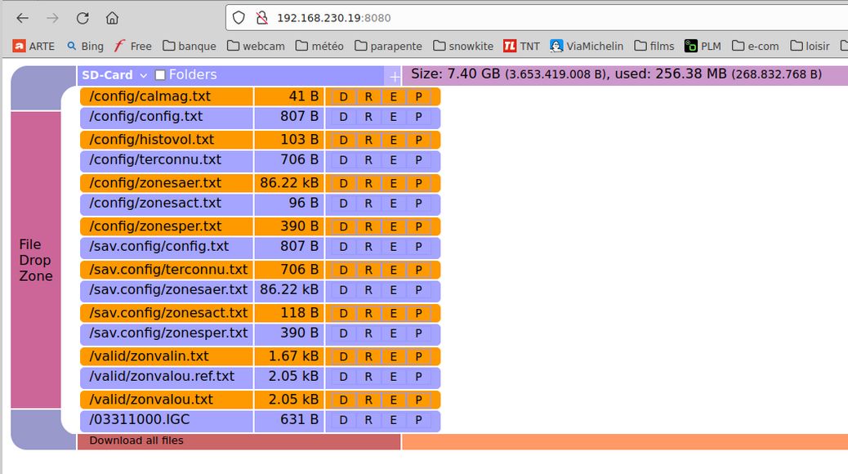
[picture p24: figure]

Remarque 2 : En mode calibration du capteur magnétique. Il faut faire des 8 avec le GnuVario jusqu’à re-démarrage (maximum de directions possible dans le sens du cap magnétique).

Il y a mise a jour du fichier /config/calmag.txt sur la carte SD qui est nécessaire au bon fonctionnement du capteur magnétique.

Bien sur, faire des 8 en position à plat ou verticale suivant la configuration firmware “à plat” “ou “suspente gauche ou droite”.

Boutons :

Gauche : mode calibration.

Central : mode wifi.

Droit : mode rando-vol.

Droit multiple : verification checksum des fichier d’altitude terrain hgt.

Gauche et droit : reboot.

# Démarrage :

Après le boot et l’initialisation du hardware, il y a démarrage du logiciel et 2 beep. S’il y a 4 beep, c’est qu’il y a un problème de carte SD. Puis il y a affichage de l’écran 0 Vz.

# Écran Vz :

Nom terrain et finesse

Cap Magnétique

à plat

Dérive Sol

Cap Sol/Gps

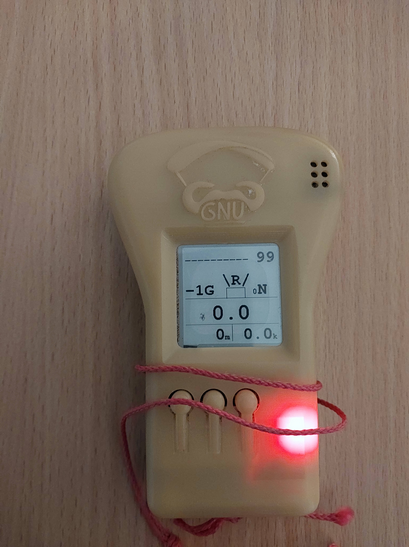
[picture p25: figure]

Temps de vol

Vitesse verticale

Cap Magnétique

Suspente droite

Finesse Sol

Cap Magnétique

Suspente gauche

Altitude

Vitesse/Hauteur Sol

Bouton central

Bouton gauche

Bouton droit

Important : Un appui long sur le bouton centre permet de re-effacer l’écran pour le remettre propre.

Boutons :

- gauche court : activer/désactiver le son d’attente gps G/S/V et/ou alarmes pénétration Tma/Zones en vol.

- gauche long : page précédente (bloqué en vol).

- central : page suivante (bloqué en vol).

- central long : raz de l’écran.

- droit court/long: démarrage forcé du vol ( Gps mode S/V) / arrêt du vol.

Cap magnétique : le cap est indiqué suivant la direction de la flèche. Il doit avoir été calibré au moins une fois (fichier /config/calmag.txt, voir séquence de boot)

Dérive sol : la dérive sol est indiquée en dizaine de degrés <<4 gauche, 5>> droite ou ^1^ tout droit. \R/ indique une reculade avec alarme sonore désactivable. << Gauche indique que l’on dérive a gauche par rapport au cap magnétique.

Nom terrain et finesse : Indique le nom du terrain d’atterrissage le plus proche et sa finesse pour l’atteindre.

Cap sol : cap issue du gps en dizaine de degrés. Indication Nord, Nord Est ...

Vitesse/Hauteur sol : vitesse issue du gps en km/h. Hauteur sol barométrique en mètres 1sec toutes les 6sec.

Vz / Finesse sol : Vz et finesse sol issue du gps et du capteur barométrique si Vz < 0 depuis plus de 10s. Ou Vz en gros. Si la Vz est cerclée de noir c’est qu’elle est négative.

Vitesse verticale : vitesse en mètres / secondes, filtrées suivant les paramètres du fichier de configuration de la carte SD. Un cerclage noir indique une descente barométrique. Agrandie en si Vz > 0 depuis moins de 10 secondes.

Altitude : Altitude barométrique recalée altitude sol en mètres. Le recalage sol est efectuée lorsque l’on est au sol avec emission d’un bit (toutes les10s) après la mise sous tension.

Temps de vol : Temps de vol en minutes.

‘-1G’ indique une attente de données GPS (voyant rouge clignotant) (émission d’un bip toutes les 5 secondes).

‘ 8S’ indique une attente de stabilisation des informations longitude, altitude, 8 satellites en vue (émission d’un bip toutes les 5 secondes).

‘10V’ indique une attente de la vitesse sol importante pour le démarrage de l’enregistrement du fichier IGC de trace GPS, 10 satellites en vue. (émission de 2 bips toutes les 5 secondes)

Les fichier IGC générés sont sous la forme MMJJHHmm.IGC dans la carte SD à la racine au rythme d’un point par seconde.

Émission de 3 beep au démarrage/arret de l’enregistrement IGC.

Pendant la phase ‘G’ ‘S’ et ‘V’ un bip est émit toutes les 5 secondes (suivant G S ou V).

Si l’on a activé le son par le bouton gauche.

Nom terrain et finesse : Conformément au fichier “/config/terconnu.txt” de la carte SD. Affichage du terrain accessible avec la plus petite finesse. Et affichage de la finesse pour l’atteindre.

Remarque 1 : Il y affichage de la TMA/CTR/Zone protégé pénétré (avec son altitude) à la place du nom terrain finesse si l’on est dedans ou proche (voir fichier /config/zonesaer.txt). (3 bips si dans la zone).

Exemple :

In TMA 2.3 al:1980m indique que l’on est en “in” on a pénétré la TMA 2.3 qui commence a une altitude de 1980m.

Zp PROTECT Reserve naturelle al: 0m indique que l’on a pénétré une zone protège (en dessous de 1000/ … /50m sol).

Remarque 2 :On peut déclencher un début de vol par le bouton droit en écran Vz. On peut arrêter un vol aussi par le bouton droit si l’on est au sol.

# Voyants LED / interrupteurs / carte SD:

A droite des 3 boutons, il y a une led de couleur rouge qui clignote quand le GPS est accroché et valide.

En charge, il y a une led bleu qui s’allume vers l’interrupteur marche/arrêt de gauche.

A coté de l’interrupteur marche/arrêt, il y a la carte SD.

# Écran Histo:

On accède à l’écran Histo par un appui sur le bouton centre âpres l écran Vz. L’écran revient à l’écran Vz au bout de 15 secondes.

L’écran 1 contient le nom du fichier Igc, la Z décollage, la Z max, la Vz Max, la Vz Min, la distance parcourue, la Vs Max et le temps total du vol. Ces informations sont issues des fichiers “/histo/nom_igc.his”.

Boutons :

- gauche long : page précédente.

- central : page suivante.

- central long : raz de l’écran.

# Écran Affichage / Archivage IGC :

Ces 2 écrans entre les écrans historique du dernier vol et gestion des TMA permettent :

- pour l’écran affichage igc, affichage des temps des fichiers IGC sur la carte SD et calcul de leur total en minutes decimale (si vol supérieur à 30 secondes).

- pour l’écran archivage (bouton gauche/droite, permet d’archiver tous les fichiers IGC de la carte qui sont à la racine. Dans le répertoire /arch/annee. Destruction des vols < 1 min.

Beeper

Antenne Gps

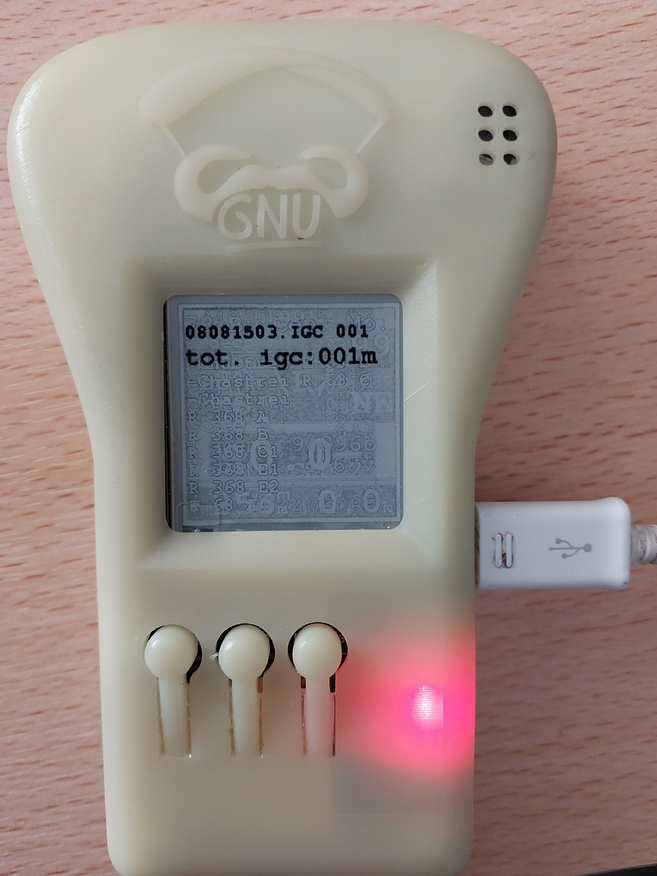
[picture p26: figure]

LED bleue de mise en charge, interrupteur M/A, carte SD

LED Gps rouge

Boutons :

- gauche long : page précédente.

- central : page suivante.

- central long : raz de l’écran (attention par temps froid).

- gauche/droit : archivage fichier igc. (central annulation)

# Écran Zone Aériennes / Modification :

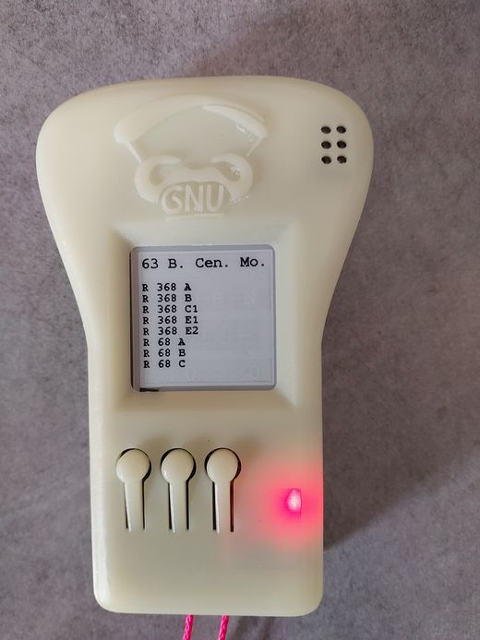
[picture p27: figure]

On accède à l’écran zone aériennes par un appui sur le bouton centre depuis histo. L’écran revient à l’écran 0 au bout de 15 secondes. Cet écran est pour la gestion des zones aériennes. On a le nombre de zones aériennes en mémoire, ainsi que le nom des zones modifiables.

Depuis l’écran zone aérienne, avec un clic droit/gauche on passe à l’écran modification pour lire ou modifier l’activation des zones. L’écran revient à l’écran Vz au bout de 15 secondes. Les boutons gauche/droit font défiler les zones, le bouton centrale peut modifier l’activation de la zone en cour (si elle est mod et pas const).

Il y a affichage à l’écran modification des informations nom, activation modifiable (mod) ou figée (const), altitude basse hors période, période début JJ-MM, période fin JJ-MM, altitude basse période semaine, altitude basse période week-end. Si la zone est « protect » ou « ffvl-prot », affichage de la hauteur sol minimale de survole (ex : Chastreix, Chaudefour, Parc des Cevennes, Gypaete barbu...)


Boutons :

- gauche long : page précédente.

- central : page suivante. si mode navigation zone : activation/désactivation Tma/Zone

- central long : raz de l’écran.

- gauche/droite : mode navigation dans Tma/Zone et retour page Tma global.

- long G/D début/fin Tma/Zones si mode navigation Tma/Zone.

La modification de l’activation de la zone est mémorisée dans le fichier /config/zonesact.txt. Et seul les zones présente dans ce fichier sont modifiable. Le format est : nom_zone;0;. Il faut donc le générer une première fois avec un éditeur de texte, pour pouvoir le modifier par la suite.


Remarque :

Les zones ne figurant pas dans ce fichier sont considérées comme toujours actives.

La totalité des zones sont dans le fichier /config/zonesaer.txt, voir plus bas pour le générer.

La configuration des périodes est dans le fichier /config/zonesper.txt. Il est de la forme :

nom zone;nom affichage;début période;fin période;alti semaine;alti week-end

ex : TMA CLERMONT 2.1;TMA CFD 2;15-03;15-10;1980;1980

Nom zone est le nom dans le fichier /config/zonesaer.txt, les 3 premiers champs. Nom affichage est le nom de remplacement à l’affichage, puis JJ-MM début période, JJ-MM fin de période, altitude période semaine, altitude période week-end.


# Écran Éditeur Configuration:

On accède à l’écran éditeur par un appui sur le bouton centre après l’écran TMA. On a alors accès a un mini éditeur du fichier de configuration. On peut ainsi modifier les variable par bouton central, puis G/D pour incrémenter / décrémenter. Ex 1: [dtu] => augmentation/diminution de 1 avec les boutons. Ex 2 : [vz_seuil_haut] => augmentation/diminution de 0,05 avec les boutons C/G/D. Les modifications sont automatiquement pris en compte et sauvegardées dans le fichier de configuration /config/config.txt dès le retour à une autre page. S’il n’y avait pas de fichier, un fichier par défaut est créé.

Boutons :

- gauche long : page précédente.

- central : page suivante. si mode navigation variables : mode modification/navigation variable.

- central long : raz de l’écran (attention par temps froid).

- gauche/droite : navigation dans variable et sortie de navigation variable. Incrémentation/décrémentation variable si mode modification.

- long G/D début/fin variable si mode navigation variable.

# Écran Tma Dessous:

On accède à l’écran Tma dessous par un appui sur le bouton centre après l’écran éditeur. On a alors accès à la Tma sous laquelle on est, avec son altitude. Ainsi que les coordonnées du point gps en cours.

Boutons :

- gauche long : page précédente.

- central : page suivante. Annulation mémorisation point.

- central long : raz de l’écran (attention par temps froid).

- gauche/droite : mémorisation point courant dans le fichier des terrains connus. Exemple : mémoriser un nouveau terrain d’atterrissage.

# Écran Système :

On accède à l’écran système par un appui sur le bouton centre âpres l’écran Tma dessous. L’écran revient à l’écran Vz au bout de 15 secondes. Cet écran est plus informations système avec date et heure, cap magnétique, pourcentage d’utilisation core 0 et 1, température à l’intérieur du boîtier, mémoire libre en octets, tension batterie, et numéro du firmware. Pour info, une zone aérienne prend de 1 à quelques ko suivant sa taille. Il y a donc de la marge dans le cas ci-dessous.


Boutons :

- gauche long : page précédente.

- central : page suivante.

# Fichier de configuration SDCard/config/config.txt :

Le fichier de configuration doit être placé dans le dossier /config a la racine de la carte SD. La carte SD contient aussi les fichier IGC générés par un vol (ou un faux vol de 12 secondes).


Compléter les informations nécessaires dans ce fichier. Les # sont des commentaires, pour le mot de passe, ssid, pilote et voile les ‘_’ sont remplacés par des blancs/espaces.

Le fichier est généré automatiquement si vous passer une fois en page mini éditeur s’il n’existait pas auparavant avec les valeurs par défaut.

[coef_filtre_alti_baro] : filtrage alti baro, valeur [0,1[, 0.999 donne un très grand filtrage mais un léger retard dans la valeur. 0. ne filtre rien et donne par conséquent des beep intempestifs. Mettre 0.85 pour un filtrage correct.

[vitesse_igc_kmh] : vitesse sol de déclenchement de l’enregistrement. Début de vol déclenché au bout de temps_igc_sec secondes de vitesse successive supérieur à (12km/h par défaut). S’il y a faux départs de vols cause imprécision gps, ne pas bouger le temps de la détection de stationnarité (quelques secondes). Il y a alors redémarrage des taches automatiquement en mode S/V.

[vz_igc_ms] : + ou - vitesse verticale pour déclencher un vol (0,7 par défaut, 2 consécutives).

[vz_seuil_haut] : Vz ascendante de déclenchement des beeps aiguës (0,2 par défaut).

[vz_seuil_bas] : Vz descendante de déclenchement des beeps grave (-2,5 par défaut).

[vz_seuil_max] : Vz ascendante des beep vario maximum très aiguës (4 par défaut).

[alarme_reculade] : activation alarme sonore reculade (désactive par défaut).

[dtu] : heure a ajouter a l’heure gps pour le nom des fichiers *.igc.

[ssid_ru] : nom wifi pour téléchargement des IGC via navigateur web. (underscores remplacés par des espaces)

[passwd_ru] : mot de passe wifi (underscores remplacés par des espaces)

[pilote_ru] : nom de pilote dans le fichier igc (underscores remplacés par des espaces)

[voile_ru] : nom de voile dans le fichier igc (underscores remplacés par des espaces)

# Fichier de terrains connus SDCard/config/terconnu.txt :


Comme vous pouvez le voir, ce fichier liste les terrains connus avec leur nom de 10 caractères maximum ainsi que leur coordonnes. Utile pour avoir la finesse du terrain le plus proche. Et pour générer les zones aériennes autour de ces points. (avec le logiciel CompZoneAerienne, voir plus bas)

# Fichier de calibration SDCard/config/calmag.txt :

Ce fichier est généré automatiquement par appuis au boot sur le bouton gauche. Faire des 8 avec le boîtier jusqu’au redémarrage pour calibrer le capteur magnétique.

# Fichier d’historique de vol SDCard/config/histovol.txt :

Ce fichier est généré automatiquement à chaque nouveau vol. Il est lu pour afficher l’écran 1. Sa forme est la même que celle dur fichier “/config/config.txt”.

# Fichier IGC :

Les fichier IGC sont téléchargeable en mode wifi (voir séquence de boot) et peuvent être visualisés sur le web avec https://e-logbook.org par exemple. Ils contiennent les dates et positions pour chaque seconde. L’altitude GPS est fausse a 250m près souvent, c’est pour cela que je ne la met plus. Il contient aussi l’altitude barométrique qui est recalée altitude sol pendant la phase S stabilisation (il est donc important de laisser le vario au sol pendant cette phase). Cette dernière est assez précise (10cm normalement) pour peut que l’on ai laissé le GPS immobile pendant la phase S, le temps qu’il se cale bien en lat/lon pour extraire la bonne altitude des fichier *.hgt. On a alors un fichier IGC précis à quelques mètres. Que l’on peut convertir en kml avec http://meles.work/igc/igc.html.

# Carte SD :

La carte SD doit etre formaté en fat16/fat32 les fichiers “/config/terconnu.txt”, “/config/config.txt”, “/config/calmag.txt”, “/config/zonesaer.txt”, “/config/zonesact.txt” et “/config/zonesper.txt”. Et les fichiers generes “/config/calmag.txt” et “/histo/nom_igc.his”. Les fichiers *.IGC sont créées à la racine.

Elle contient aussi les fichiers de validation de zone “/valid/zonvalin.txt” et le fichier généré au boot wifi “/valid/zonvalout.txt”.

Important : Pensez a installer aussi les fichier de hauteur sol *.hgt, pour toute la france, dans le repertoire "/config/hgtdata". Ceci est obligatoire car il y a recalage d’altitude barométrique avec ces fichiers avant le decollage ( https://www.viewfinderpanoramas.org/Coverage%20map%20viewfinderpanoramas_org3.htm ).

# Rechargement du GnuVario :

Utiliser un cable micro-usb. Une lumière bleue doit être visible par les interstices du boîtier. Une recharge complète prend plusieurs heures. La tension de la batterie doit être à 4,3v en pleine charge (3,7v déchargée)(c’est un peut faux pour une lipo, mais le pont de résistances est ainsi). La tension de la batterie est affichée a l’écran de boot ou en page sys.

# Le Gps :

Bien entendu le Gps accroche mieux en pleine nature qu’en ville, en terrain découvert que sous les arbres, par ciel clair que pluvieux, à l’arrêt qu’en déplacement. Attendre le clignotement de la LED rouge et l’affichage d’une altitude cohérente à l’écran avant de faire le vol (recalage altitude barométrique par altitude sol jusqu’à la stabilisation gps).

# Les zones aériennes et le fichier SDCard/config/zonesaer.txt :

Les zones aériennes qui sont traversées sont affichées en lieux et place de “terrain connu accessible”. Si l’on traverse une zone aérienne, il y a affichage du nom de la zone ainsi de que sont altitude minimale avec une alarme sonore (l’altitude est fonction de la zone, de la date en ou hors périodes, et de la semaine ou du week-end dans la période). L’alarme sonore est activable/désactivable par le bouton du milieu.

Peut de zones tiennent en mémoire du GnuVario. Donc, pour ce faire, il faut prendre le fichier PlatformIO/Projects/CompZoneAerienne/data/20240615_ffvl-cfd.geojson (disponible sur le net, fichier generer par “Pascal Bazile” http://pascal.bazile.free.fr/paraglidingFolder/divers/GPS/OpenAir-Format/download.php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 ) et le découper avec le programme PlatformIO/Projet/CompZoneAerienne/CompZoneAerienne qui compresse les zones à fort nombre de points.

Utilisation : CompZoneAerienne lat_centre_deg lon_centre_deg rayon_km > zonesaert.txt. Ou CompZoneAerienne –batch terconnu.txt rayon_km > zonesaert.txt pour utilisation du fichier des terrains connus. Le programme enregistre alors dans le fichier toutes les zones coupant les cercles définit par leur centres et rayons des points connus. Il suffit de placer ce fichier sur la carte SD/config.

Attention : Si le fichier est trop gros, il plante le GnuVario au boot lors de sa lecture. C’est pour cela qu’il y a des zones réduites en nombre de points par CompZoneAerienne, Ceci est fait lors de la génération du fichier. Comme pour les zones protégées “PROTECT” qui ont un énorme nombre de points de définition (1800 pour Chaudefour)(Validation Gnuplot très acceptable). L’algorithme utilisé est la suppression des points proches d’une droite.

De plus, pour gagner en mémoire il y a un algorithme de compression de données de float 32bits vers short 16bits dans le firmware. Les zones ont ainsi une résolution variable de 1 à 7 mètres par rapport aux zones du fichier 20240615_ffvl-cfd.geojson (http://pascal.bazile.free.fr/paraglidingFolder/divers/GPS/OpenAir-Format/download.php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). En moyenne la résolution est de 1,95metres. Si il y a un problème de compression short il y a beep et reboot.

Remarque : Les fichiers *.hgt nécessaire au calcul de la hauteur sol sont a mettre dans le répertoire “SdCard/config/hgtdata” (à télécharger sur https://www.viewfinderpanoramas.org/Coverage%20map%20viewfinderpanoramas_org3.htm). Il y a test de présence au démarrage du centre de la France (pui de dome).

Important : Le GnuVario a été activement teste pour différent sites d‘Auvergne, a différentes périodes, altitudes et marges XY Z. Je décline toutes responsabilité quand à sa fiabilité à ce sujet (on est jamais à l’abri d’un oubli dans l’algorithme), en Auvergne et encore moins dans une autre région. Les zones étant bien imbriquées, vérifier par procédure de test, au moins un point par zone, que le comportement est correct chez vous. Pour cela il y a 2 façons :

- Rappel : dans la page “histo ecran 1”, la zone et le plafond courant sont affichés.

- Utiliser le fichier /valid/zonevalin.txt de la carte Sd. Puis booter en wifi. Il y a alors génération de /valid/zonevalou.txt avec les résultats.

Zonevalin.txt est de la forme :

#ville;lon,lat;annee,mois,jour;altitude,marge_xy,marge_z;zone a_active,zone_b_active;

Zonevalou.txt est de la forme :

numéro_ligne;ville;date;TMA;altitude_plafond;alarme_générée;


Remarque :

Il y a un fichier généré en mode wifi /valid/zonomout.txt qui donne la correspondance des noms de zones du fichier json => nom interne GnuVario. Utile pour renseigner le fichier des zones activables /config/zonesact.txt.

# Pour les développeur qui veulent recompiler :

Pour ceux qui veulent recompiler le programme pour leur écran ou autre. Installer Visual studio code sur linux (ou Windows) comme préconiser sur https://prunkdump.github.io/GNUVario-TTGO-T5-website/code/ide_platformio.html (avec plateforme IO et board espressif ESP32 Dev module).

Copier les dossiers de https://github.com/gitberthe/BertheVario dans ~/Documents/PlatformIO/Projets.

Ouvrir le projet BertheVarioPlatformIO. Modifier les fichiers désirer, et en particulier les // commentaires des ecrans dans les fichier *.h du repertoire Screen sections ESP32. Ou les “#define GNU_VARIO_GRIS” dans BertheVarioPlatformIO/src/BertheVario.h et ses différents #define DEBUG_XYZ.

Puis compiler/uploader le firmware (petite fleche en bas à gauche de VSCode, port /dev/ttyACM0 sous linux) de préférence sans la carte SD. Ca reboot automatiquement le GnuVario.

Débogage par “Moniteur Serie”.

Important : la librairie du capteur magnétique Mpu9250 a été modifiée pour la lecture a 5hz sinon sa plante le capteur, donc attention si vous la réinstallée (apparemment avec github et pull):

- modifier "/BertheVarioPlatformIO/.pio/libdeps/esp32dev/MPU9250/MPU9250.h" ligne 85 : 0x06 en 0x02.

- modifier aussi "BertheVarioPlatformIO/.pio/libdeps/esp32dev/ESP32 File Manager for Generation Klick ESPFMfGK/src/ESPFMfGKGa.cpp" ligne 6 : #include <crc32.h> en <CRC32.h>.

Remarque : Pour ceux qui utilisait le GnuVario firmware d’origine et veulent toujours l’utiliser. Je leur conseil de rajouter un mutex entre le son et les différents capteurs, ça ne gêne en rien le fonctionnement dans le programme. Mais ça évite qu’il plante et reboot aléatoirement dans les ascendances, ou ça bip, au bout d’une demie heure.

Rappel : Pour ceux qui veulent recompiler CompZoneAerienne et ainsi générer leur propre zones, le faire sous codeblocks, aussi bien sous windows que sous liux.

Pour windows voir le programme et ses .dll déjà compilées dans le dépôt https://github.com/gitberthe/BertheVario

# Le mode randonnée pour ne plus se perdre :


Trace du fichier Gpx

Echelle de la carte

Nom trace courante

Zoom + et -

Nord magnetique

Cap Gps

Position courante

Le mode randonnée est un mode de guidage terrestre pour rejoindre un décollage inconnu par exemple.

Il est accessible au boot par l’appui sur le bouton droit (rappel : gauche calibration magnétique, centre filemanager wifi, gauche et droite reboot).

Au démarrage, il y a acquisition du Gps. Puis une fois le Gps fonctionnant, il y a lecture des fichiers *.GPX du répertoire /SdCard/Gpx, ainsi que du fichier des terrains connus et d’un fichier similaire ptremarq.txt. Et affichage quelques secondes des traces/points les plus proches (rappel on peut télécharger les fichiers par wifi, drag&drop).

Suivant la position Gps, la trace/point gpx la plus proche est chargée en mémoire au bout de quelques secondes. On peut sélectionner une autre trace par les boutons gauche/droite/centre. Le guidage alors commence.

A l’écran on a :

- Le nom de la trace du fichier gpx (8 caractères maximum + 3 pour l’extension). Le nom de la trace est celui dans le fichier (la balise <name>) et peut être modifiée avec un éditeur de texte standard.

- La grande ligne est le nord magnétique issu du capteur magnétique (qui doit être calibré bien sur). Dans mon cas le haut du GnuVario mais ça dépend de la compilation (fichier BerheVario.h #define VARIO_CAP_MAG_A_PLAT 1 2 ou 3).

- La trace gpx, orientée au nord, à l’échelle indiquée en mètres carrés pour la surface de l’écran.

- Les touches gauche/droite pour zoom fois 2, divisé par 2.

- le centre de l’écran est la position actuelle.

- La petite ligne est le cap gps.

Donc en alignant le nord magnétique en haut de la carte on peut se situer par rapport à la trace. Le petit rond de la trace indique le début de la trace. Pour ma part c’est souvent l’atterrissage.

On peut aussi mettre la ligne du cap gps en direction de la trace pour la rejoindre. Ou parallèle à la trace pour la suivre.

D’autre part, avec le bouton centre, on affiche la page informations pour quelques secondes. Avec les distances/altitudes positive faites et restantes.

On peut aussi orienter la carte au cap gps lors de la marche (boutons long G/D ou double appui).

Je crée souvent les traces avec https://www.visugpx.com/editgpx.

Boutons :

Centre : validation trace si menu. page info rando si mode trace.

Centre long : raz écran.

Gauche/Droite : sélection trace si menu. Zoom+/-.

Gauche/Droite long : cap nord/gps.

A vos bâtons de marche…

# Les logiciels annexe :

Le logiciel CompZoneAerienne est primordiale pour le GnuVario. Il permet de generer le fichier zoneaer.txt, à placer dans la carte SD/config, avec le fichier de zones national de “Pascal Bazile” http://pascal.bazile.free.fr/paraglidingFolder/divers/GPS/OpenAir-Format/download.php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 ) .

Il ya a deux modes de generation :

CompZoneAerienne lat_centre_deg lon_centre_deg rayon_km > zonesaert.txt.

Ou

CompZoneAerienne –batch terconnu.txt rayon_km > zonesaert.txt

Le logiciel GestHgt permet de ne retenir que les fichiers Hgt de la france. Il cree aussi les checksum des dales Hgt récuperée sur : https://www.viewfinderpanoramas.org/Coverage%20map%20viewfinderpanoramas_org3.htm.

Le logiciel IgcRead permet d’avoir des info sur un fichier igc. Il genere aussi un fichier kml pour voir sa trace dans GoogleEarth.

Merci aux premiers concepteurs du GnuVario

et

Bon vols.

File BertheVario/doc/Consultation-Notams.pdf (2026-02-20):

# Site du Service de l’Information Aéronautique (SIA)

## Consultation des Notams


Lien : https://www.sia.aviation-civile.gouv.fr/

1. Cliquer sur « préparation de vol »
2. Cliquer sur « sofiabriefing »


3. Cliquer sur « préparation »
4. Cliquer sur « local »


5. Paramétrer la date et l’heure souhaitées(attention, des notams peuvent figurer 72h avant car étendus sur une plage temporelle très large, et d’autres la veille = à consulter jusqu’au dernier moment) ;
6. Mentionner le code OACI de l’aéroport de Clermont-Ferrand (LFLC) pour situer le vol et les notams afférents.
7. Cliquer sur Notam Trajet


8. Paramétrer plage de durée (4 chiffres = H et min); le plafond (115 en parapente chez nous) ; le rayon autour de l’aéroport(NM = nautic mille = Mille nautique = unité de mesure maritime et aérienne= 1,852 Kms)
a. Mettre 30 ce qui ratisse assez large autour d’Aulnat

Activation R368 le 19/04 de 12h à 13h30 (UTC)

Les heures sont toujours exprimées en heure UTC :

= + 2h en France métropolitaine à l’heure d’été ;

= + 1h à l’heure d’hiver.

## Décrypter un NOTAM


Consulter ensuite la zone centre, la carte AZBA et les SUP AIP

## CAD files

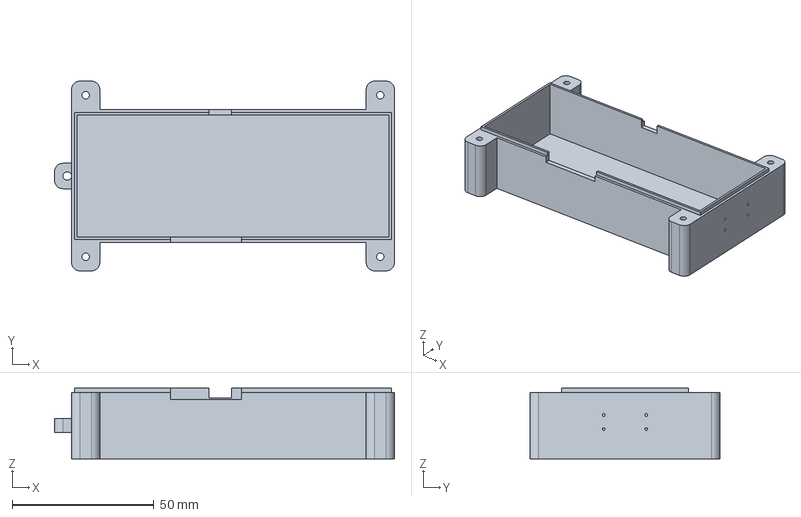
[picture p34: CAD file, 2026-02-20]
BertheVario213/FreeCad/BertheVario213_corps-v4.FCStd
120.0 x 67.0 x 25.0 mm

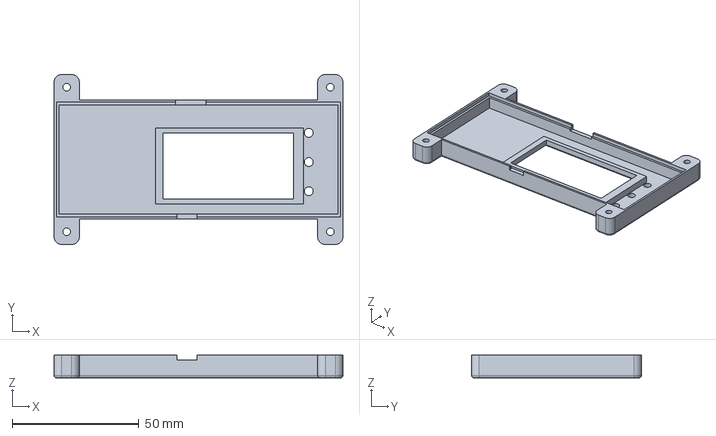
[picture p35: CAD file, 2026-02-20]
BertheVario213/FreeCad/BertheVario213_capot-v4.FCStd
114.0 x 67.0 x 9.00 mm

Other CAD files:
BertheVario213/FreeCad/carte-esp32/T5_V2.3_2.13.FCStd
BertheVario213/FreeCad/BertheVario213_corps-v4-Body.stl
BertheVario213/FreeCad/BertheVario213_capot-v4-Body.stl
BertheVario213/FreeCad/old/BertheVario213_corps-v3-Body.stl
BertheVario213/FreeCad/old/BertheVario213_corps-v3.FCStd
BertheVario213/FreeCad/old/BertheVario213_capot-v3-Body.stl

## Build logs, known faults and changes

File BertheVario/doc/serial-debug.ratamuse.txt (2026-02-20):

Value = 348.94
varioscreenObjects_154.cpp:626: valueMax = 9999.00
varioscreenObjects_154.cpp:635: value = 348.94
displayStep
displaystep - objectCount  : 32
loop
VarioImuTwoWire UpdateAlti : 348.93
Temperature : 14.79
Accel : -0.20
Kalman Update
VarioData Update
Alti : 348.93
Temperature : 14.79
Accel : -0.20
Velocity : -0.09
Calibrated alti : 348.94
Baro Alti : 348.93
Temperature : 14.79
accelerateur : -0.20
Kalman Alti : 348.94
Kalman Vario : -0.09
ComputeHeight Alti : 348.94, Lat : -1.00, Long :-1.00
AGL Directory exists : 0
AGL Height 348.94
Beeper - setvelocity : -0.09
Beeper - BEEP_TYPE_GLIDING
ScreenDigit : setValue
Value = 348.94
varioscreenObjects_154.cpp:626: valueMax = 9999.00
varioscreenObjects_154.cpp:635: value = 348.94
ScreenDigit : setValue
Value = -0.09
varioscreenObjects_154.cpp:626: valueMax = 9.90
varioscreenObjects_154.cpp:635: value = -0.09
Beeper - setTone : BEEP_TYPE_GLIDING
tone - frequence : 0
AUDIO_AMP_ENABLE / pin : 19
AUDIO_AMP_ENABLE HIGH
ToneESP32 volume : 3
Sat : 0
ScreenDigit : setValue
Value = 0.00
varioscreenObjects_154.cpp:626: valueMax = 99.00
varioscreenObjects_154.cpp:2019: voltage = 2334
VarioState : 0
Compas : 253 - W
ScreenDigit : setValue
Value = 253.00
varioscreenObjects_154.cpp:626: valueMax = 999.00
varioscreenObjects_154.cpp:635: value = 253.00
ScreenText : setValue
Value = W
Height : 348.94
ScreenDigit : setValue
Value = 348.94
varioscreenObjects_154.cpp:626: valueMax = 9999.00
varioscreenObjects_154.cpp:635: value = 348.94
displayStep
displaystep - objectCount  : 32
loop
VarioImuTwoWire UpdateAlti : 349.09
Temperature : 14.79
Accel : -0.18
Kalman Update
VarioData Update
Alti : 349.09
Temperature : 14.79
Accel : -0.18
Velocity : -0.09
Calibrated alti : 348.95
Baro Alti : 349.09
Temperature : 14.79
accelerateur : -0.18
Kalman Alti : 348.95
Kalman Vario : -0.09
ComputeHeight Alti : 348.95, Lat : -1.00, Long :-1.00
AGL Directory exists : 0
AGL Height 348.95
Beeper - setvelocity : -0.09
Beeper - BEEP_TYPE_GLIDING
ScreenDigit : setValue
Value = 348.95
varioscreenObjects_154.cpp:626: valueMax = 9999.00
varioscreenObjects_154.cpp:635: value = 348.95
ScreenDigit : setValue
Value = -0.09
varioscreenObjects_154.cpp:626: valueMax = 9.90
varioscreenObjects_154.cpp:635: value = -0.09
Beeper - setTone : BEEP_TYPE_GLIDING
tone - frequence : 0
AUDIO_AMP_ENABLE / pin : 19
AUDIO_AMP_ENABLE HIGH
ToneESP32 volume : 3
Sat : 0
ScreenDigit : setValue
Value = 0.00
varioscreenObjects_154.cpp:626: valueMax = 99.00
varioscreenObjects_154.cpp:2019: voltage = 2331
VarioState : 0
Compas : 253 - W
ScreenDigit : setValue
Value = 253.00
varioscreenObjects_154.cpp:626: valueMax = 999.00
varioscreenObjects_154.cpp:635: value = 253.00
ScreenText : setValue
Value = W
Height : 348.95
ScreenDigit : setValue
Value = 348.95
varioscreenObjects_154.cpp:626: valueMax = 9999.00
varioscreenObjects_154.cpp:635: value = 348.95
displayStep
displaystep - objectCount  : 32
loop
VarioImuTwoWire UpdateAlti : 349.17
Temperature : 14.79
Accel : -0.20
Kalman Update
VarioData Update
Alti : 349.17
Temperature : 14.79
Accel : -0.20
Velocity : -0.09
Calibrated alti : 348.95
Baro Alti : 349.17
Temperature : 14.79
accelerateur : -0.20
Kalman Alti : 348.95
Kalman Vario : -0.09
ComputeHeight Alti : 348.95, Lat : -1.00, Long :-1.00
AGL Directory exists : 0
AGL Height 348.95
Beeper - setvelocity : -0.09
Beeper - BEEP_TYPE_GLIDING
ScreenDigit : setValue
Value = 348.95
varioscreenObjects_154.cpp:626: valueMax = 9999.00
varioscreenObjects_154.cpp:635: value = 348.95
ScreenDigit : setValue
Value = -0.09
varioscreenObjects_154.cpp:626: valueMax = 9.90
varioscreenObjects_154.cpp:635: value = -0.09
Beeper - setTone : BEEP_TYPE_GLIDING
tone - frequence : 0
AUDIO_AMP_ENABLE / pin : 19
AUDIO_AMP_ENABLE HIGH
ToneESP32 volume : 3
Sat : 0
ScreenDigit : setValue
Value = 0.00
varioscreenObjects_154.cpp:626: valueMax = 99.00
varioscreenObjects_154.cpp:2019: voltage = 2287
VarioState : 0
Compas : 253 - W
ScreenDigit : setValue
Value = 253.00
varioscreenObjects_154.cpp:626: valueMax = 999.00
ScreenText : setValue
Value = W
Height : 348.95
ScreenDigit : setValue
Value = 348.95
varioscreenObjects_154.cpp:626: valueMax = 9999.00
varioscreenObjects_154.cpp:635: value = 348.95
displayStep
displaystep - objectCount  : 32
loop
VarioImuTwoWire UpdateAlti : 349.08
Temperature : 14.79
Accel : -0.22
Kalman Update
VarioData Update
Alti : 349.08
Temperature : 14.79
Accel : -0.22
Velocity : -0.09
Calibrated alti : 348.96
Baro Alti : 349.08
Temperature : 14.79
accelerateur : -0.22
Kalman Alti : 348.96
Kalman Vario : -0.09
ComputeHeight Alti : 348.96, Lat : -1.00, Long :-1.00
AGL Directory exists : 0
AGL Height 348.96
Beeper - setvelocity : -0.09
Beeper - BEEP_TYPE_GLIDING
ScreenDigit : setValue
Value = 348.96
varioscreenObjects_154.cpp:626: valueMax = 9999.00
varioscreenObjects_154.cpp:635: value = 348.96
ScreenDigit : setValue
Value = -0.09
varioscreenObjects_154.cpp:626: valueMax = 9.90
varioscreenObjects_154.cpp:635: value = -0.09
Beeper - setTone : BEEP_TYPE_GLIDING
tone - frequence : 0
AUDIO_AMP_ENABLE / pin : 19
AUDIO_AMP_ENABLE HIGH
ToneESP32 volume : 3
Sat : 0
ScreenDigit : setValue
Value = 0.00
varioscreenObjects_154.cpp:626: valueMax = 99.00
varioscreenObjects_154.cpp:2019: voltage = 2346
VarioState : 0
Compas : 252 - W
ScreenDigit : setValue
Value = 252.00
varioscreenObjects_154.cpp:626: valueMax = 999.00
varioscreenObjects_154.cpp:635: value = 252.00
ScreenText : setValue
Value = W
Height : 348.96
ScreenDigit : setValue
Value = 348.96
varioscreenObjects_154.cpp:626: valueMax = 9999.00
varioscreenObjects_154.cpp:635: value = 348.96
displayStep
displaystep - objectCount  : 32
loop
VarioImuTwoWire UpdateAlti : 348.90
Temperature : 14.79
Accel : -0.18
Kalman Update
VarioData Update
Alti : 348.90
Temperature : 14.79
Accel : -0.18
Velocity : -0.09
Calibrated alti : 348.96
Baro Alti : 348.90
Temperature : 14.79
accelerateur : -0.18
Kalman Alti : 348.96
Kalman Vario : -0.09
ComputeHeight Alti : 348.96, Lat : -1.00, Long :-1.00
AGL Directory exists : 0
AGL Height 348.96
Beeper - setvelocity : -0.09
Beeper - BEEP_TYPE_GLIDING
ScreenDigit : setValue
Value = 348.96
varioscreenObjects_154.cpp:626: valueMax = 9999.00
varioscreenObjects_154.cpp:635: value = 348.96
ScreenDigit : setValue
Value = -0.09
varioscreenObjects_154.cpp:626: valueMax = 9.90
varioscreenObjects_154.cpp:635: value = -0.09
Beeper - setTone : BEEP_TYPE_GLIDING
tone - frequence : 0
AUDIO_AMP_ENABLE / pin : 19
AUDIO_AMP_ENABLE HIGH
ToneESP32 volume : 3
Sat : 0
ScreenDigit : setValue
Value = 0.00
varioscreenObjects_154.cpp:626: valueMax = 99.00
varioscreenObjects_154.cpp:2019: voltage = 2326
VarioState : 0
Compas : 252 - W
ScreenDigit : setValue
Value = 252.00
varioscreenObjects_154.cpp:626: valueMax = 999.00
varioscreenObjects_154.cpp:635: value = 252.00
ScreenText : setValue
Value = W
Height : 348.96
ScreenDigit : setValue
Value = 348.96
varioscreenObjects_154.cpp:626: valueMax = 9999.00
varioscreenObjects_154.cpp:635: value = 348.96
displayStep
displaystep - objectCount  : 32
loop
VarioImuTwoWire UpdateAlti : 348.98
Temperature : 14.79
Accel : -0.20
Kalman Update
VarioData Update
Alti : 348.98
Temperature : 14.79
Accel : -0.20
Velocity : -0.09
Calibrated alti : 348.96
Baro Alti : 348.98
Temperature : 14.79
accelerateur : -0.20
Kalman Alti : 348.96
Kalman Vario : -0.09
ComputeHeight Alti : 348.96, Lat : -1.00, Long :-1.00
AGL Directory exists : 0
AGL Height 348.96
Beeper - setvelocity : -0.09
Beeper - BEEP_TYPE_GLIDING
ScreenDigit : setValue
Value = 348.96
varioscreenObjects_154.cpp:626: valueMax = 9999.00
varioscreenObjects_154.cpp:635: value = 348.96
ScreenDigit : setValue
Value = -0.09
varioscreenObjects_154.cpp:626: valueMax = 9.90
varioscreenObjects_154.cpp:635: value = -0.09
Beeper - setTone : BEEP_TYPE_GLIDING
tone - frequence : 0
AUDIO_AMP_ENABLE / pin : 19
AUDIO_AMP_ENABLE HIGH
ToneESP32 volume : 3
Sat : 0
ScreenDigit : setValue
Value = 0.00
varioscreenObjects_154.cpp:626: valueMax = 99.00
varioscreenObjects_154.cpp:2019: voltage = 2332
VarioState : 0
Compas : 252 - W
ScreenDigit : setValue
Value = 252.00
varioscreenObjects_154.cpp:626: valueMax = 999.00
ScreenText : setValue
Value = W
Height : 348.96
ScreenDigit : setValue
Value = 348.96
varioscreenObjects_154.cpp:626: valueMax = 9999.00
varioscreenObjects_154.cpp:635: value = 348.96
displayStep
displaystep - objectCount  : 32
loop
VarioImuTwoWire UpdateAlti : 348.86
Temperature : 14.79
Accel : -0.16
Kalman Update
VarioData Update
Alti : 348.86
Temperature : 14.79
Accel : -0.16
Velocity : -0.09
Calibrated alti : 348.96
Baro Alti : 348.86
Temperature : 14.79
accelerateur : -0.16
Kalman Alti : 348.96
Kalman Vario : -0.09
ComputeHeight Alti : 348.96, Lat : -1.00, Long :-1.00
AGL Directory exists : 0
AGL Height 348.96
Beeper - setvelocity : -0.09
Beeper - BEEP_TYPE_GLIDING
ScreenDigit : setValue
Value = 348.96
varioscreenObjects_154.cpp:626: valueMax = 9999.00
varioscreenObjects_154.cpp:635: value = 348.96
ScreenDigit : setValue
Value = -0.09
varioscreenObjects_154.cpp:626: valueMax = 9.90
varioscreenObjects_154.cpp:635: value = -0.09
Beeper - setTone : BEEP_TYPE_GLIDING
tone - frequence : 0
AUDIO_AMP_ENABLE / pin : 19
AUDIO_AMP_ENABLE HIGH
ToneESP32 volume : 3
Sat : 0
ScreenDigit : setValue
Value = 0.00
varioscreenObjects_154.cpp:626: valueMax = 99.00
varioscreenObjects_154.cpp:2019: voltage = 2335
VarioState : 0
Compas : 253 - W
ScreenDigit : setValue
Value = 253.00
varioscreenObjects_154.cpp:626: valueMax = 999.00
varioscreenObjects_154.cpp:635: value = 253.00
ScreenText : setValue
Value = W
Height : 348.96
ScreenDigit : setValue
Value = 348.96
varioscreenObjects_154.cpp:626: valueMax = 9999.00
varioscreenObjects_154.cpp:635: value = 348.96
displayStep
displaystep - objectCount  : 32
loop
VarioImuTwoWire UpdateAlti : 349.03
Temperature : 14.79
Accel : -0.22
Kalman Update
VarioData Update
Alti : 349.03
Temperature : 14.79
Accel : -0.22
Velocity : -0.09
Calibrated alti : 348.96
Baro Alti : 349.03
Temperature : 14.79
accelerateur : -0.22
Kalman Alti : 348.96
Kalman Vario : -0.09
ComputeHeight Alti : 348.96, Lat : -1.00, Long :-1.00
AGL Directory exists : 0
AGL Height 348.96
Beeper - setvelocity : -0.09
Beeper - BEEP_TYPE_GLIDING
ScreenDigit : setValue
Value = 348.96
varioscreenObjects_154.cpp:626: valueMax = 9999.00
varioscreenObjects_154.cpp:635: value = 348.96
ScreenDigit : setValue
Value = -0.09
varioscreenObjects_154.cpp:626: valueMax = 9.90
varioscreenObjects_154.cpp:635: value = -0.09
Beeper - setTone : BEEP_TYPE_GLIDING
tone - frequence : 0
AUDIO_AMP_ENABLE / pin : 19
AUDIO_AMP_ENABLE HIGH
ToneESP32 volume : 3
Sat : 0
ScreenDigit : setValue
Value = 0.00
varioscreenObjects_154.cpp:626: valueMax = 99.00
varioscreenObjects_154.cpp:2019: voltage = 2323
VarioState : 0
Compas : 251 - W
ScreenDigit : setValue
Value = 251.00
varioscreenObjects_154.cpp:626: valueMax = 999.00
varioscreenObjects_154.cpp:635: value = 251.00
ScreenText : setValue
Value = W
Height : 348.96
ScreenDigit : setValue
Value = 348.96
varioscreenObjects_154.cpp:626: valueMax = 9999.00
varioscreenObjects_154.cpp:635: value = 348.96
displayStep
displaystep - objectCount  : 32
loop
VarioImuTwoWire UpdateAlti : 349.10
Temperature : 14.79
Accel : -0.16
Kalman Update
VarioData Update
Alti : 349.10
Temperature : 14.79
Accel : -0.16
Velocity : -0.09
Calibrated alti : 348.96
Baro Alti : 349.10
Temperature : 14.79
accelerateur : -0.16
Kalman Alti : 348.96
Kalman Vario : -0.09
ComputeHeight Alti : 348.96, Lat : -1.00, Long :-1.00
AGL Directory exists : 0
AGL Height 348.96
Beeper - setvelocity : -0.09
Beeper - BEEP_TYPE_GLIDING
ScreenDigit : setValue
Value = 348.96
varioscreenObjects_154.cpp:626: valueMax = 9999.00
varioscreenObjects_154.cpp:635: value = 348.96
ScreenDigit : setValue
Value = -0.09
varioscreenObjects_154.cpp:626: valueMax = 9.90

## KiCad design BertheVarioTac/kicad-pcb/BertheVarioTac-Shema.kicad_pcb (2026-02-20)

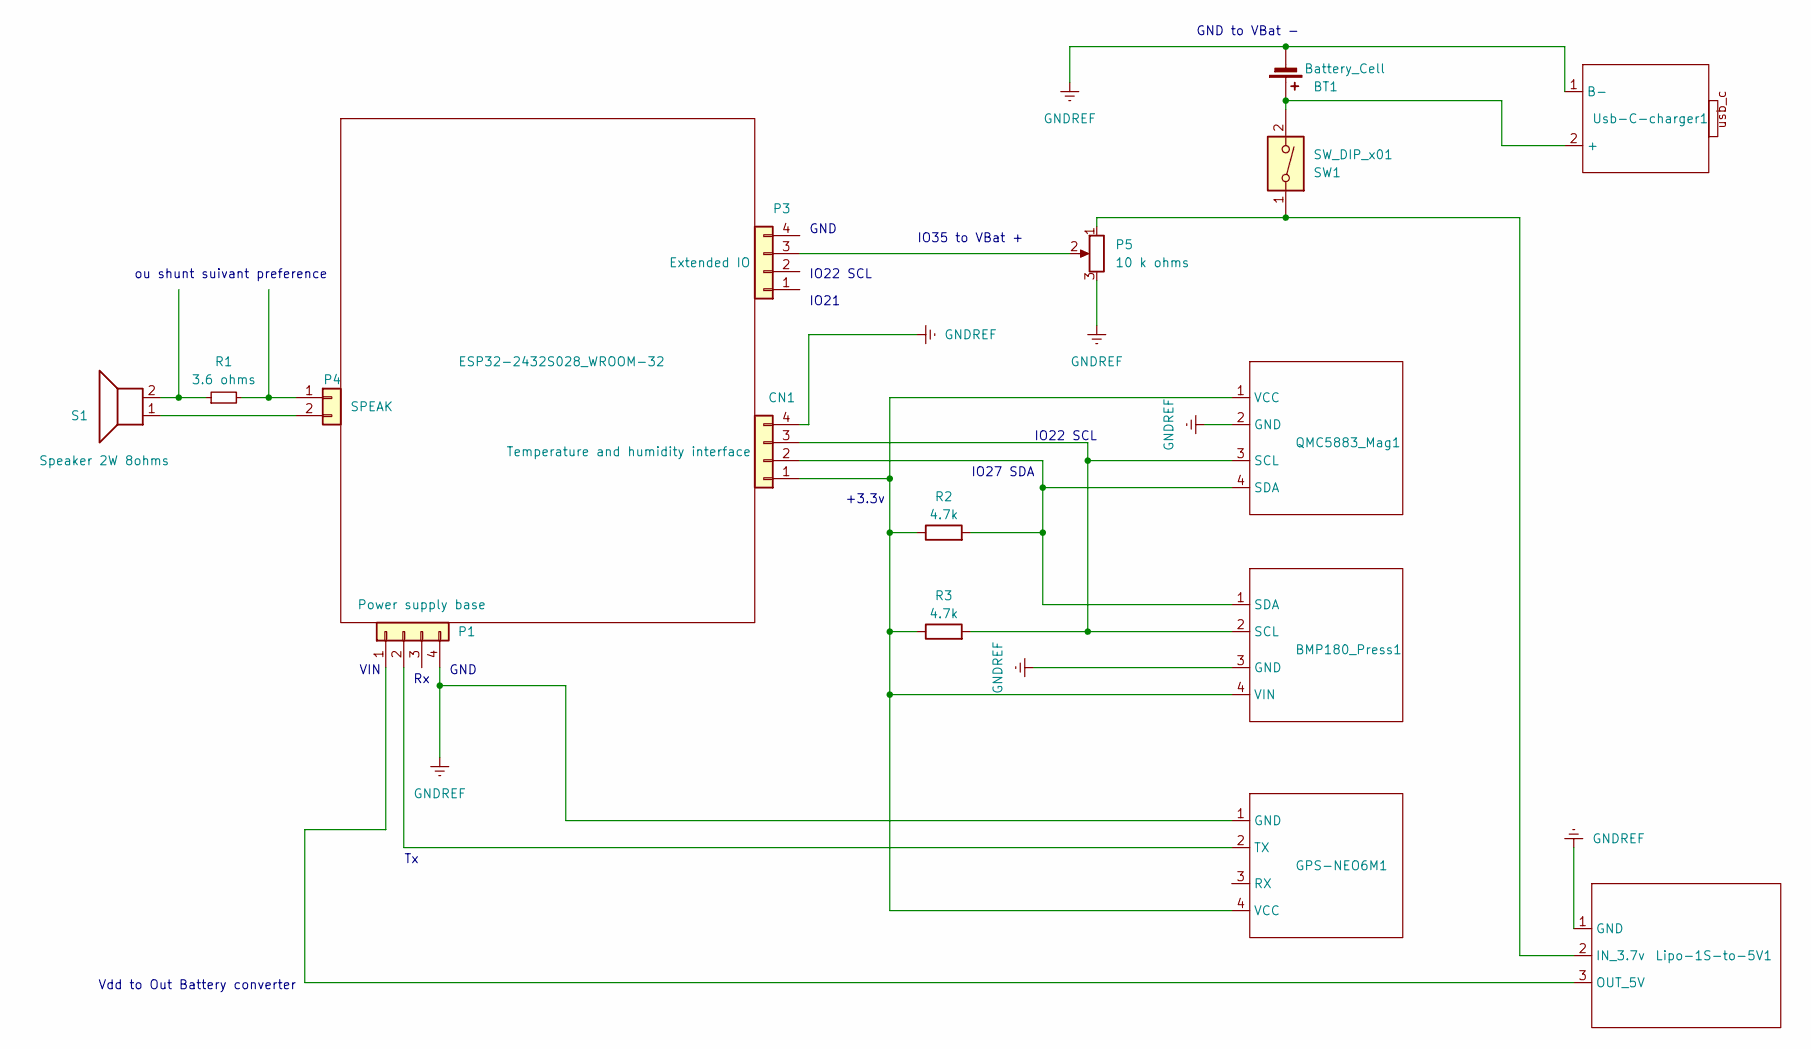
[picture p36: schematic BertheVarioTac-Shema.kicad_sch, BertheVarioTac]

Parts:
BMP180_Press1: BMP180
BT1: Battery_Cell; batterie
CN1: Temperature and humidity interface; 4 trous standard
ESP32-2432S028_WROOM-32: -; KiCad-Logo2_5mm_SilkScreen
GPS-NEO6M1: -; GPSNEO6V2
Lipo-1S-to-5V1: -; 1S-to-5v
P1: Power supply base; 4 trous standard
P3: Extended IO; 4 trous standard
P4: SPEAK; 2 trous standard
P5: 10 k ohms; potentiometre
QMC5883_Mag1: QMC5883
R1: 3.6 ohms; R_Axial_DIN0207_L6.3mm_D2.5mm_P10.16mm_Horizontal
R2, R3: 4.7k; R_47
S1: Speaker 2W 8ohms; 2 trous standard
SW1: SW_DIP_x01; 2 trous standard
Usb-C-charger1: -; Usb-C-Charger

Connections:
GNDREF: BMP180_Press1.3 (GND), BT1.2 (-), CN1.4, GPS-NEO6M1.1 (GND), Lipo-1S-to-5V1.1 (GND), P1.4, P5.3, QMC5883_Mag1.2 (GND), Usb-C-charger1.1 (B-)
unnamed: BMP180_Press1.2 (SCL), CN1.3, QMC5883_Mag1.3 (SCL), R3.2
unnamed: BMP180_Press1.1 (SDA), CN1.2, QMC5883_Mag1.4 (SDA), R2.2
unnamed: BMP180_Press1.4 (VIN), CN1.1, GPS-NEO6M1.4 (VCC), QMC5883_Mag1.1 (VCC), R2.1, R3.1
unnamed: BT1.1 (+), SW1.2, Usb-C-charger1.2 (+)
unnamed: GPS-NEO6M1.2 (TX), P1.2
unnamed: Lipo-1S-to-5V1.2 (IN_3.7v), P5.1, SW1.1
unnamed: Lipo-1S-to-5V1.3 (OUT_5V), P1.1
unnamed: P3.3, P5.2
unnamed: P4.1, R1.2
unnamed: P4.2, S1.1
unnamed: R1.1, S1.2

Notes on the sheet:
IO22 SCL
Vdd to Out Battery converter
GND
GND to VBat -
IO27 SDA
IO21
IO35 to VBat +
+3.3v
VIN
ou shunt suivant preference

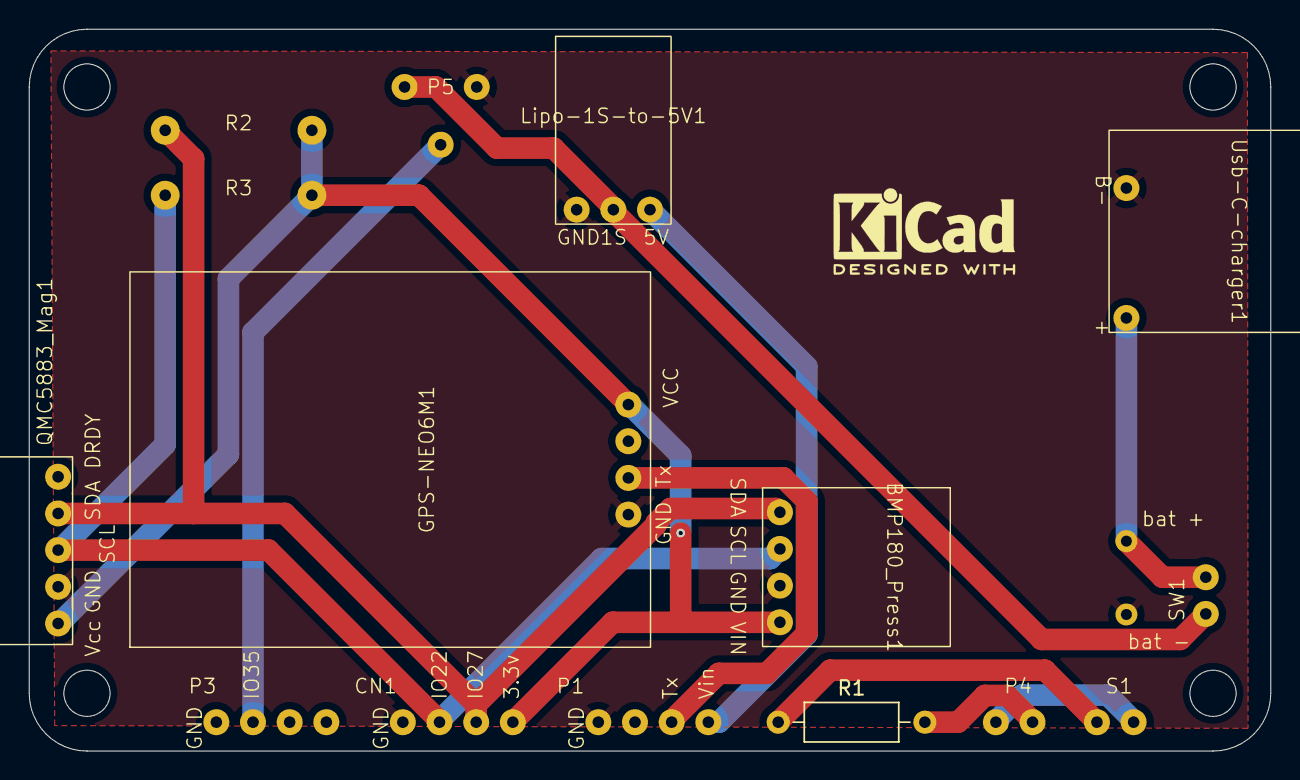
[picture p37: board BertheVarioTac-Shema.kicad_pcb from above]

Board: 2 copper layers, 86.0 x 50.0 mm, 17 parts (0 on the bottom side), 12 nets.

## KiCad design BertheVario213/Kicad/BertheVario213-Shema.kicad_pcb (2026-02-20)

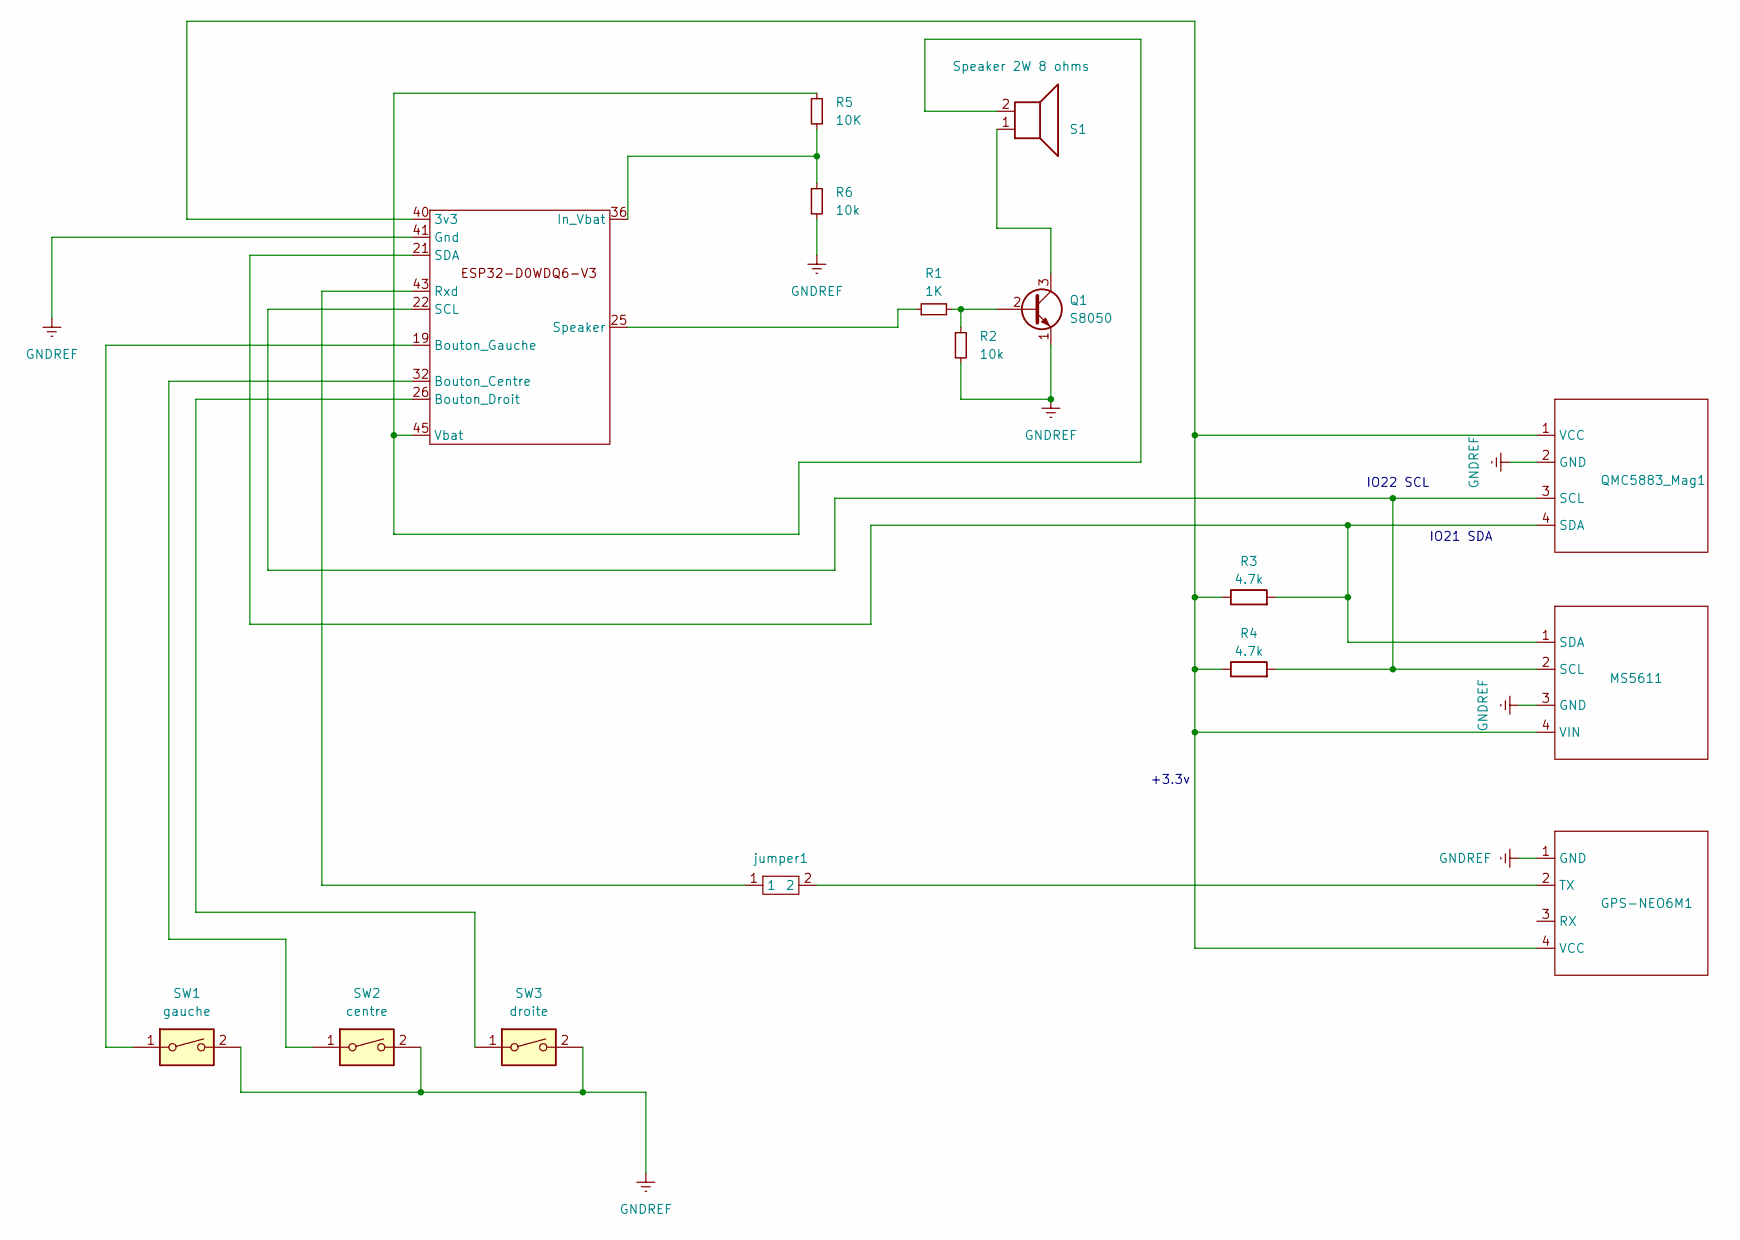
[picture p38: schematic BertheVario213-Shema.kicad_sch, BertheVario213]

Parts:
GPS-NEO6M1: -; GPSNEO6V2
MS5611: MS5611
Q1: S8050
QMC5883_Mag1: QMC5883
R1: 1K; R_47
R2, R6: 10k; R_47
R3, R4: 4.7k; R_47
R5: 10K; R_47
S1: Speaker 2W 8 ohms; 2 trous standard
SW1: gauche; switch
SW2: centre; switch
SW3: droite; switch
U1: ESP32-D0WDQ6
jumper1: jumper

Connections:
GNDREF: GPS-NEO6M1.1 (GND), MS5611.3 (GND), Q1.1 (E), QMC5883_Mag1.2 (GND), R2.2, R6.2, SW1.2, SW2.2, SW3.2, U1.41 (Gnd)
unnamed: GPS-NEO6M1.2 (TX), jumper1.2
unnamed: GPS-NEO6M1.4 (VCC), MS5611.4 (VIN), QMC5883_Mag1.1 (VCC), R3.1, R4.1, U1.40 (3v3)
unnamed: MS5611.2 (SCL), QMC5883_Mag1.3 (SCL), R4.2, U1.22 (SCL)
unnamed: MS5611.1 (SDA), QMC5883_Mag1.4 (SDA), R3.2, U1.21 (SDA)
unnamed: Q1.2 (B), R1.2, R2.1
unnamed: Q1.3 (C), S1.1
unnamed: SW2.1, U1.32 (Bouton_Centre)
unnamed: SW3.1, U1.26 (Bouton_Droit)
unnamed: SW1.1, U1.19 (Bouton_Gauche)
unnamed: R5.2, R6.1, U1.36 (In_Vbat)
unnamed: U1.43 (Rxd), jumper1.1
unnamed: R1.1, U1.25 (Speaker)
unnamed: R5.1, S1.2, U1.45 (Vbat)

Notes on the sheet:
IO22 SCL
IO21 SDA
+3.3v

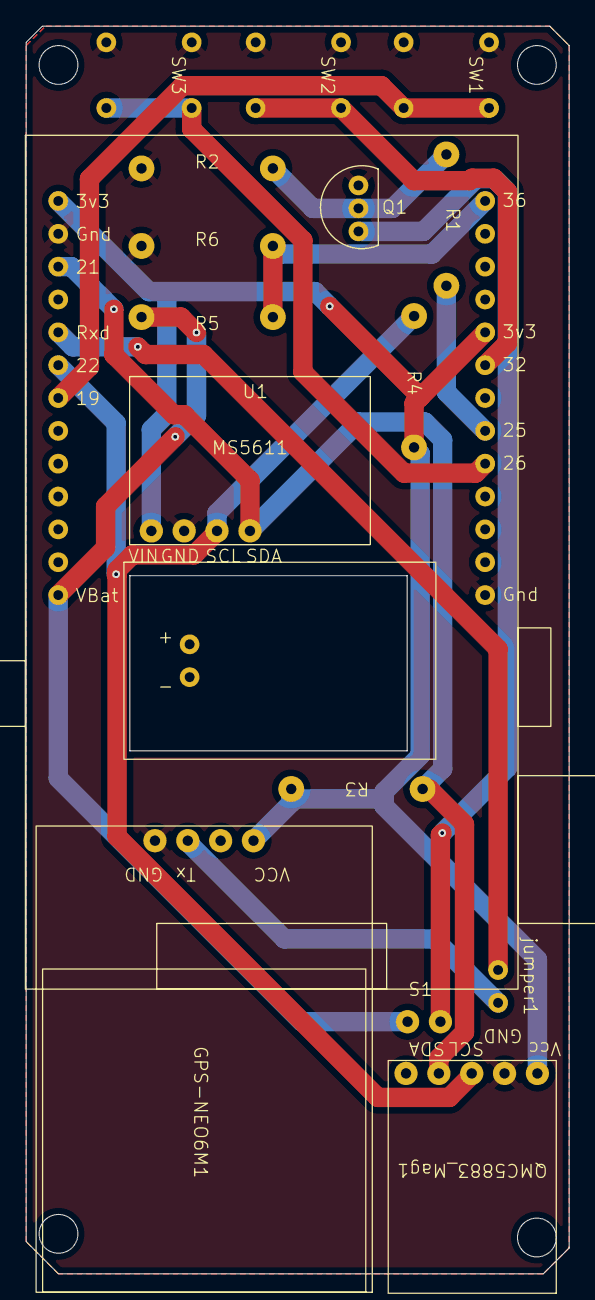
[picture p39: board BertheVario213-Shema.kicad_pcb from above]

Board: 2 copper layers, 42.0 x 96.5 mm, 16 parts (0 on the bottom side), 14 nets.

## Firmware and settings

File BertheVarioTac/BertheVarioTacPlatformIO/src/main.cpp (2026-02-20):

////////////////////////////////////////////////////////////////////////////////
/// \file main.cpp
///
/// \brief loop de l'application
///
/// \date creation     : 21/09/2024
/// \date modification : 08/07/2025 suppression xc_track et limite zone xy alti
/// \date modification : 08/07/2025
///

#include "BertheVarioTac.h"

////////////////////////////////////////////////////////////////////////////////
/// \brief setup ESP32-2432S028
void setup()
{
//Serial.begin(115200);
Serial.begin(9600);
#ifdef NO_GPS_DEBUG
 Serial.begin(9600);
 Serial.println("Debugage on" ) ;
#endif
//goto fin ;

// lancement tache son
g_GlobalVar.LanceTacheSound() ;
delay(500) ;
g_GlobalVar.BeepOk() ;

// init pin d'entree de tension
g_GlobalVar.InitBattery() ;

// initialisation de l'ecran tactile
g_tft.InitScreen() ;

// affaichage vbat
AfficheEcranDebut() ;

// init sdcard
g_GlobalVar.InitSDCard() ;

// test pdd hgt
g_GlobalVar.TestPddGroundZ() ;

// Init BUS I2C
g_GlobalVar.InitI2C() ;

// lecture fichier terrains
g_GlobalVar.m_TerrainArr.LireFichierTerrains(TERRAIN_FCH) ;

// lecture fichier zones aeriennes
g_GlobalVar.m_ZonesAerAll.LectureFichiers() ;

// lecture fichier de configuration
g_GlobalVar.m_Config.LectureFichier() ;
g_GlobalVar.m_Config.FreeVect() ;

// init capteur de pression
g_GlobalVar.m_pCapteurPression->InitCapteur() ;

// init capteur magnetique
g_GlobalVar.m_QMC5883Mag.InitMagnetique() ;

#ifndef NO_GPS_DEBUG
 // init port serie GPS
 g_GlobalVar.InitGps() ;

 // lancement tache gps
 g_GlobalVar.LanceTacheGps(true) ;
#else
 g_GlobalVar.m_DureeVolMin = ATTENTE_MESSAGE_GPS ;
#endif // NO_GPS_DEBUG

// lancement tache beep
g_GlobalVar.LanceTacheVarioCapBeep() ;

// raz de l'ecran
g_GlobalVar.m_Screen.ScreenRaz(false) ;

// desactivation du wifi pour autonomie batterie
esp_wifi_stop() ;
esp_wifi_deinit() ;

/*
// mode economie d'energie
// -DCONFIG_PM_ENABLE
esp_pm_config_t pm_config ;
pm_config.max_freq_mhz = 100; // 160 240
pm_config.min_freq_mhz = 40;
pm_config.light_sleep_enable = true ;
ESP_ERROR_CHECK(esp_pm_configure(&pm_config));
*/
}


////////////////////////////////////////////////////////////////////////////////
/// \brief boucle sans fin
void loop()
{
// variables
static int count_10hz = 0 ;
static bool WifiSetupFileMgr = true ;
static bool WifiSetupOta = true ;

////////////////////////
// si mode wifi file mgr
if ( g_GlobalVar.m_ModeHttp )
    {
    // si init wifi
    if ( WifiSetupFileMgr )
        {
        // init file manager
        WifiSetupFileMgr = false ;
        WifiInitFileMgr() ;
        }

    g_pfilemgr->handleClient();

    // si ecran pressé on reboot
    if ( !(count_10hz++%100) )
        {
        // traitement de touch pad
        g_GlobalVar.m_Screen.HandleTouchScreen() ;

        // scan les boutons tactiles
        g_GlobalVar.m_Screen.HandleButtons() ;

        if ( g_GlobalVar.m_Screen.IsCenterPressed() )
            g_GlobalVar.Reboot() ;
        }

    return ;
    }

////////////////////
// si mode wifi ota
if ( g_GlobalVar.m_ModeHttpOta )
    {
    // si init wifi
    if ( WifiSetupOta )
        {
        WifiSetupOta = false ;
        WifiInitOta() ;
        }

    WifiOtaHandle() ;

    // si ecran pressé on reboot
    if ( !(count_10hz++%100) )
        {
        // traitement de touch pad
        g_GlobalVar.m_Screen.HandleTouchScreen() ;

        // scan les boutons tactiles
        g_GlobalVar.m_Screen.HandleButtons() ;

        if ( g_GlobalVar.m_Screen.IsCenterPressed() )
            g_GlobalVar.Reboot() ;
        }

    return ;
    }

/////////////////
// ecran de debut
if( (millis()-g_GlobalVar.m_temps_debut)/1000 < 5 )
    {
    g_GlobalVar.m_Screen.m_MutexTft.PrendreMutex() ;
     AfficheEcranDebut() ;
    g_GlobalVar.m_Screen.m_MutexTft.RelacherMutex() ;
    delay( 1000 ) ;
    return ;
    }

static bool once = true ;
if ( once )
    {
    once = false ;
    g_GlobalVar.BeepOk() ;
    delay( 200 ) ;
    g_GlobalVar.BeepOk() ;
    }

////////
// 10 hz
unsigned long time = millis() ;

// traitement de touch pad
//g_GlobalVar.m_Screen.m_MutexTft.PrendreMutex() ;
 g_GlobalVar.m_Screen.HandleTouchScreen() ;
//g_GlobalVar.m_Screen.m_MutexTft.RelacherMutex() ;

// scan les boutons tactiles
g_GlobalVar.m_Screen.m_MutexTft.PrendreMutex() ;
 bool Action = g_GlobalVar.m_Screen.HandleButtons() ;
g_GlobalVar.m_Screen.m_MutexTft.RelacherMutex() ;

// affichage des boutons
g_GlobalVar.m_Screen.m_MutexTft.PrendreMutex() ;
g_tft.startWrite();
 g_GlobalVar.m_Screen.AfficheButtons() ;
g_tft.endWrite();
g_GlobalVar.m_Screen.m_MutexTft.RelacherMutex() ;

// compteur 10 hz
count_10hz++ ;

// 10 hz
while ( (millis() - time) < 100 )
    delay( DELAY_ATTENTE_IDLE ) ;

///////
// 2 hz
if ( (count_10hz%5) && !Action )
    return ;

Serial.println( "*** loop ***" ) ;

// si page Vz en cours
bool SpeedScreen = g_GlobalVar.m_Screen.GetEtatAuto() == CAutoPages::ECRAN_0_Vz ;

// affichage des pages
g_GlobalVar.m_Screen.m_MutexTft.PrendreMutex() ;
if ( SpeedScreen )
    g_tft.startWrite();
g_GlobalVar.m_Screen.SequencementPages() ;
if ( SpeedScreen )
    g_tft.endWrite();
g_GlobalVar.m_Screen.m_MutexTft.RelacherMutex() ;

// pour eviter mutex accet carte sd/ecran
if ( g_GlobalVar.m_Screen.GetEtatAuto() == CAutoPages::ECRAN_9c_RandoVolInfo )
    g_GlobalVar.m_TerrainPosCur.m_AltiBaroRec = g_GlobalVar.m_Hgt2Agl.GetGroundZ( g_GlobalVar.m_TerrainPosCur.m_Lon , g_GlobalVar.m_TerrainPosCur.m_Lat ) ;

#ifdef NO_GPS_DEBUG
 static int count_debug = 0 ;
 Serial.print( count_debug++) ;
 Serial.println(" mode debug") ;
#endif

// mode economie d'energie
//esp_light_sleep_start() ;

//tft.sleep() ;
//tft.powerSaveOn() ;
//g_tft.startWrite(); // bug avec carte SD si utilisation
//tft.beginTransaction();

// sequencement des pages
//g_GlobalVar.m_Screen.SequencementPages() ;

// raz de l'etat des boutons tactiles
//g_GlobalVar.m_Screen.RazButtons() ;

//g_tft.endWrite(); // bug avec carte SD si utilisation

//tft.clearClipRect()  ;
//tft.fillRect(0, 0,240,320,TFT_WHITE);
//tft.clearDisplay() ;
//tft.powerSaveOff() ;
//tft.wakeup() ;
//tft.endTransaction();

//uxTaskGetStackHighWaterMark(NULL) ;
}

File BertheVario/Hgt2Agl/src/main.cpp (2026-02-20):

////////////////////////////////////////////////////////////////////////////////
/// \file main.cpp
///
/// \brief Programme de test de lecture de fichier Hgt pour AGL.
///
/// \date creation     : 01/04/2024
/// \date modification : 01/04/2024
///

#include <iostream>

using namespace std;

#include "CHgt2Agl.h"

////////////////////////////////////////////////////////////////////////////////
/// \brief
int main(int argc , char *argv[] )
{
// pdd
float PddLat = 45.772396 ;
float PddLon = 2.964061  ;
// vichy
float ViLat = 46.1239268 ;
float ViLon = 3.4203712  ;

// aiguille du midi
float MiLat = 45. + 52./60 + 43./3600. ;
float MiLon = 6. + 53./60 + 14./3600. ;

// aiguille du midi
float MbLat = 45.878723 ;
float MbLon = 6.887614 ;

// aiguille du midi
float PtLat = 45.885989 ;
float PtLon = 2.727933 ;

// corent
float CoLat = 45.660355 ;
float CoLon = 3.179634 ;

// zp sancy
float ZpLat = 45.491927 ;
float ZpLon = 2.740171 ;

CHgt2Agl Hgt2Agl ;
int PddAlti = Hgt2Agl.GetGroundZ( PddLon , PddLat ) ;
int ViAlti = Hgt2Agl.GetGroundZ( ViLon , ViLat ) ;
int MiAlti = Hgt2Agl.GetGroundZ( MiLon , MiLat ) ;
int MbAlti = Hgt2Agl.GetGroundZ( MbLon , MbLat ) ;
int PtAlti = Hgt2Agl.GetGroundZ( PtLon , PtLat ) ;
int CoAlti = Hgt2Agl.GetGroundZ( CoLon , CoLat ) ;
int ZpAlti = Hgt2Agl.GetGroundZ( ZpLon , ZpLat ) ;

cout << "pdd(1465) alti:"   << PddAlti << endl;
cout << "vichy() alti:" << ViAlti << endl;
cout << "midi(3842) alti:"  << MiAlti << endl;
cout << "mb(4809) alti:"  << MbAlti << endl;
cout << "pt(686) alti:"  << PtAlti << endl;
cout << "co(616) alti:"  << CoAlti << endl;
cout << "Zp(1141) alti:"  << ZpAlti << endl;
return 0;
}

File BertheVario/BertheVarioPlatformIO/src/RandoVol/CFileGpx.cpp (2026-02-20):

////////////////////////////////////////////////////////////////////////////////
/// \file CFileGpx.cpp
///
/// \brief
///
/// \date creation     : 14/01/2025
/// \date modification : 18/01/2025
///

#include "../BertheVario.h"

////////////////////////////////////////////////////////////////////////////////
/// \brief
CFileGpx::~CFileGpx()
{
if ( m_pVecTrack != NULL )
    delete m_pVecTrack ;
}

////////////////////////////////////////////////////////////////////////////////
/// \brief lit un fichier et remplit la trace
void CFileGpx::LireFichier(bool AvecAlt)
{
char TmpChar[1000] = "" ;

// raz precedent
m_TrackName = "" ;

// ouverture fichier
File file = SD.open(m_FileName);
if ( !file )
    {
    Serial.println("Failed to open file for reading");
    return;
    }

if ( m_pVecTrack == NULL )
    m_pVecTrack = new CLGArray<StPoint> ;
else
    m_pVecTrack->SetSize(0) ;
m_pVecTrack->SetGrow( 100 ) ;

// lecture fichier
int ic = 0 ;
while(file.available())
    {
    char c = file.read() ;
    TmpChar[ic++] = c ;
    if ( c == '\n' )
        {
        TmpChar[ic++] = 0 ;
        ic = 0 ;
        TraiteLigne( TmpChar , AvecAlt ) ;
        }
    }
TmpChar[ic++] = 0 ;
TraiteLigne( TmpChar , AvecAlt ) ;

// fermeture fichier
file.close() ;

m_pVecTrack->FreeExtra() ;
}

////////////////////////////////////////////////////////////////////////////////
/// \brief Calcul de la loupe de depart et de la distance minimale a un point de
/// la trace.
void CFileGpx::SetDistanceFrom( const StPoint PtCur )
{
m_DistFrom = 500.*500. ;
float DeltaLL = 0 ;

m_Barycenter.m_Lat = 0 ;
m_Barycenter.m_Lon = 0 ;
for ( int i = 0 ; i < m_pVecTrack->GetSize() ; i++ )
    {
    m_Barycenter.m_Lat += (*m_pVecTrack)[i].m_Lat ;
    m_Barycenter.m_Lon += (*m_pVecTrack)[i].m_Lon ;

    float DistFrom = sqrtf( powf(PtCur.m_Lat-(*m_pVecTrack)[i].m_Lat,2.0) + powf(PtCur.m_Lon-(*m_pVecTrack)[i].m_Lon,2.0) ) ;
    if ( m_DistFrom > DistFrom )
        m_DistFrom = DistFrom ;
    }
m_Barycenter.m_Lat /= m_pVecTrack->GetSize() ;
m_Barycenter.m_Lon /= m_pVecTrack->GetSize() ;

// delta de lat/lon
for ( int i = 0 ; i < (*m_pVecTrack).GetSize() ; i++ )
    {
    float Dist = fabsf(m_Barycenter.m_Lat - (*m_pVecTrack)[i].m_Lat) ;
    if ( DeltaLL < Dist )
        DeltaLL = Dist ;
    Dist = fabsf(m_Barycenter.m_Lon - (*m_pVecTrack)[i].m_Lon) ;
    if ( DeltaLL < Dist )
        DeltaLL = Dist ;
    }
m_SlopeMax = 3.*DeltaLL/SLOPE_MAX_DIV ;
}

////////////////////////////////////////////////////////////////////////////////
/// \brief Traite une ligne de *.gpx
void CFileGpx::TraiteLigne( char * Ligne , bool AvecAlt )
{
// nom piste
if ( m_TrackName == "" && strstr( Ligne , "<name>" ) != NULL )
    {
    strtok( Ligne , "<>" ) ;
    strtok( NULL , "<>" ) ;
    m_TrackName = strtok( NULL , "<>" ) ;
    }
// point de piste
else if ( strstr( Ligne , "<trkpt " ) != NULL )
    {
    StPoint Pts ;
    strtok( Ligne , "\"" ) ;
    Pts.m_Lat = atof( strtok( NULL , "\"" ) ) ;
    strtok( NULL , "\"" ) ;
    Pts.m_Lon = atof( strtok( NULL , "\"" ) ) ;
    m_pVecTrack->Add( Pts ) ;
    //Serial.print( Pts.m_Lat ) ;
    //Serial.print( " " ) ;
    //Serial.println( Pts.m_Lon ) ;
    }
// altitude du dernier point
else if ( AvecAlt && strstr( Ligne , "<ele>" ) != NULL && m_pVecTrack->GetSize() )
    {
    StPoint & Pts = (*m_pVecTrack)[m_pVecTrack->GetSize()-1] ;
    strtok( Ligne , "<>" ) ;
    strtok( NULL , "<>" ) ;
    Pts.m_Alt = atof( strtok( NULL , "<>" ) ) ;
    //Serial.println( Pts.m_Alt ) ;
    }
}

////////////////////////////////////////////////////////////////////////////////
/// \brief Renvoie la distance et l'altitude restante en metres.
void CFileGpx::GetInfo( const StPoint PtCur , float & AltitudeRest , float & DistanceRest , float & AltitudeFait , float & DistanceFait )
{
// determination du pt proche
int iPtProche = 0 ;
float DistProche = 360. ;
for ( int i = 0 ; i < m_pVecTrack->GetSize() ; i++ )
    {
    float Dist = powf(PtCur.m_Lat-(*m_pVecTrack)[i].m_Lat,2.0) + powf(PtCur.m_Lon-(*m_pVecTrack)[i].m_Lon,2.0) ;
    if ( DistProche > Dist )
        {
        DistProche = Dist ;
        iPtProche = i ;
        }
    }

// init altitude distance restante
DistanceRest = DistanceMetre( PtCur , (*m_pVecTrack)[iPtProche] ) ;
AltitudeRest = (*m_pVecTrack)[iPtProche].m_Alt - PtCur.m_Alt ;
if ( AltitudeRest < 0 )
    AltitudeRest = 0 ;
for ( int i = iPtProche + 1 ; i < m_pVecTrack->GetSize() ; i++ )
    {
    DistanceRest += DistanceMetre( (*m_pVecTrack)[i-1] , (*m_pVecTrack)[i] ) ;
    float AltiPos = (*m_pVecTrack)[i].m_Alt - (*m_pVecTrack)[i-1].m_Alt ;
    if ( AltiPos > 0. )
        AltitudeRest += AltiPos ;
    }

// init altitude distance fait
DistanceFait = DistanceMetre( PtCur , (*m_pVecTrack)[iPtProche] ) ;
AltitudeFait = PtCur.m_Alt - (*m_pVecTrack)[iPtProche].m_Alt ;
if ( AltitudeFait < 0 )
    AltitudeFait = 0 ;
for ( int i = 0 ; i < iPtProche && i < m_pVecTrack->GetSize() ; i++ )
    {
    DistanceFait += DistanceMetre( (*m_pVecTrack)[i+1] , (*m_pVecTrack)[i] ) ;
    float AltiPos = (*m_pVecTrack)[i+1].m_Alt - (*m_pVecTrack)[i].m_Alt ;
    if ( AltiPos > 0. )
        AltitudeFait += AltiPos ;
    }
}

////////////////////////////////////////////////////////////////////////////////
/// \brief Renvoie la distance entre points en metres
float CFileGpx::DistanceMetre( StPoint PtA , StPoint PtB ) const
{
float DelLat = PtA.m_Lat-PtB.m_Lat ;
float DelLon = PtA.m_Lon-PtB.m_Lon ;
float DelAlt = PtA.m_Alt-PtB.m_Alt ;
float Dist = powf(DelLat*MilesParDegres*UnMileEnMetres,2.) + powf(DelLon*MilesParDegres*UnMileEnMetres,2.) + powf(DelAlt,2.) ;
return sqrtf(Dist) ;
}

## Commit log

2026-02-20 premier git 3 vario
    [BertheVario213-Shema-B_Cu.gbr, BertheVario213-Shema-B_Mask.gbr, BertheVario213-Shema-B_Paste.gbr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]
2026-02-22 ajout trace photo
2026-02-27 compensation temperature
2026-03-02 nombre de points
2026-06-11 changement de file manager
2026-06-22 ecran de boot
2026-10-13 compress zone ligne de commande
